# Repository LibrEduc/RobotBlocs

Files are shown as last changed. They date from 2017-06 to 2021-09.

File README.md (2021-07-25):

RobotBlocs
===================
tangible programmation of drawing robot, by kids for kids.

[Click here to launch video: https://mediacad.ac-nantes.fr/m/2332](https://mediacad.ac-nantes.fr/m/2332)
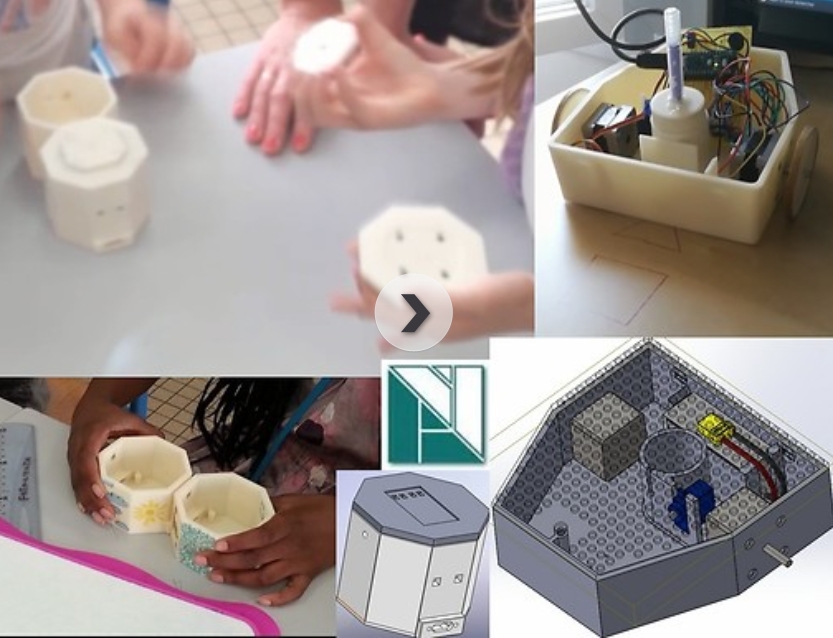
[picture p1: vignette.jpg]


**==>**[**Animation à ouvrir.**](https://github.com/technologiescollege/RobotBlocs/blob/master/principe.swf?raw=true)

Designers & developpers
----------
Chaque version du projet, chaque année, chaque groupe et chaque organisation a été différente.
Vous trouverez les noms des élèves, quand ils ont bien voulu qu'on les laisse, dans les dossiers (électronique ou Modeles_3D\Solidworks) de chaque année.

Each version of the project, each year, each group and each organisation has been different.
You will find the names of the students, when they were willing to be left, in the folders (electronic or Modeles_3D\Solidworks) of each year.

Explanation/explication
----------
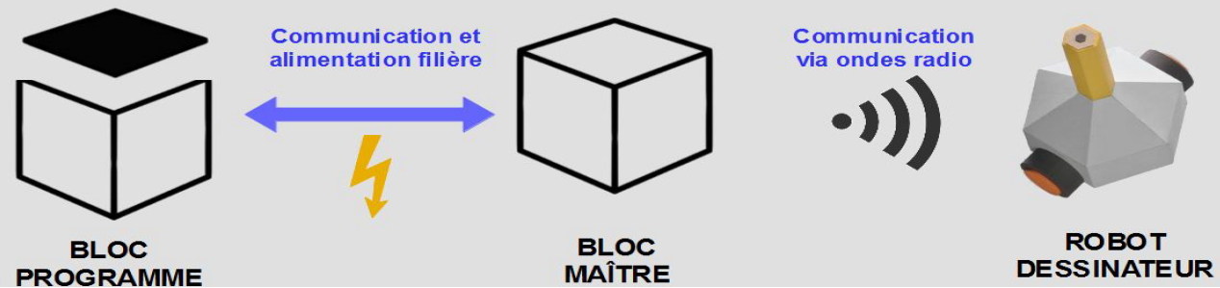
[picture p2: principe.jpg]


Les enfants jouent naturellement avec leurs mains et apprennent avec dès leurs premières années, construisant toute sorte de choses qui peuvent les amuser mais aussi en faisant ces choses ensemble. Un des avantages de la programmation tangible est qu'il rend l'idée du programme physique, afin que les enfants puissent jouer avec, le manipuler et refaire autant que voulu avant de le téléverser. La tranche d'âge visée est celle d'enfants entre 6 et 7 ans. 

Notre problématique est la suivante : "concevoir un système permettant à des enfants âgés de 6 ans ou plus, sachant lire ou pas, avec des difficultés motrices ou pas, d'apprendre les bases de la programmation et de l’algorithmique". 

A la suite de la lecture du cahier des charges fonctionnels, nous pouvons donc affirmer que nous devons concevoir un système composé de 3 sous-systèmes : 

 - un bloc maître qui transmet les informations des blocs programmes à un robot dessinateur.  
 - des blocs programmes qui auront une fonction, liée aux mouvements du robot,définie par un couvercle amovible ainsi qu'une capacité à s'emboîter entre eux afin de former une chaîne pour transmettre l'information. 
 - un robot dessinateur motorisé autonome en énergie qui possédera une partie mobile pour déplacer un crayon, d'un diamètre de 8mm à 15mm, afin de tracer des formes sur papier. Il exécutera les commandes des blocs programmes envoyées via le bloc maître.

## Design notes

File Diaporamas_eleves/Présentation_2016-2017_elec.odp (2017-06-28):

## Projet Blocs Lycée Livet -STI2D

<number>

## Présentation

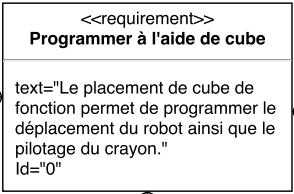
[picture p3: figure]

Développer la créativité et la réflexion.

Enfant de 5 à 6 ans.

Co-réalisation avec les ITEC.

<number>

## Présentation du projet.

COUVERCLE

BLOC

MAÎTRE

ROBOT

BLOC PROGRAMMABLE

<number>

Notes: décompose en 3 parties : couvercle interchangeable → ex: fct 2 = triangle donc la fonction résultante est faire un triangle quand couvercle sur bloc maître.

## Vidéo tutorial

<number>

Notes: Enfants vont créer une séquence en empilant les blocs les uns à la suite des autres. Rattaché au bloc maître Enfants vont enclencher le processus de démarrage. Bloc maître va compter le nombre de bloc et récupérer les fonctions dans l’ordre. Envoie au robot. Il va pouvoir reproduire les fonctions sur une feuilles de papier.

## Le robot

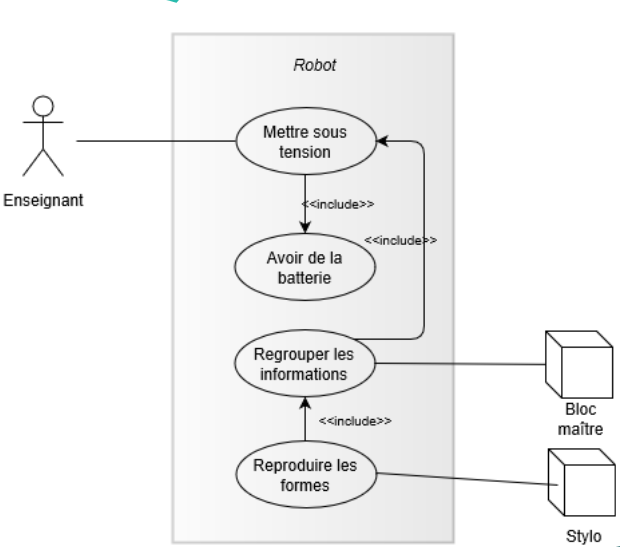
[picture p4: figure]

Diagramme de cas d’utilisation

<number>

## Le robot

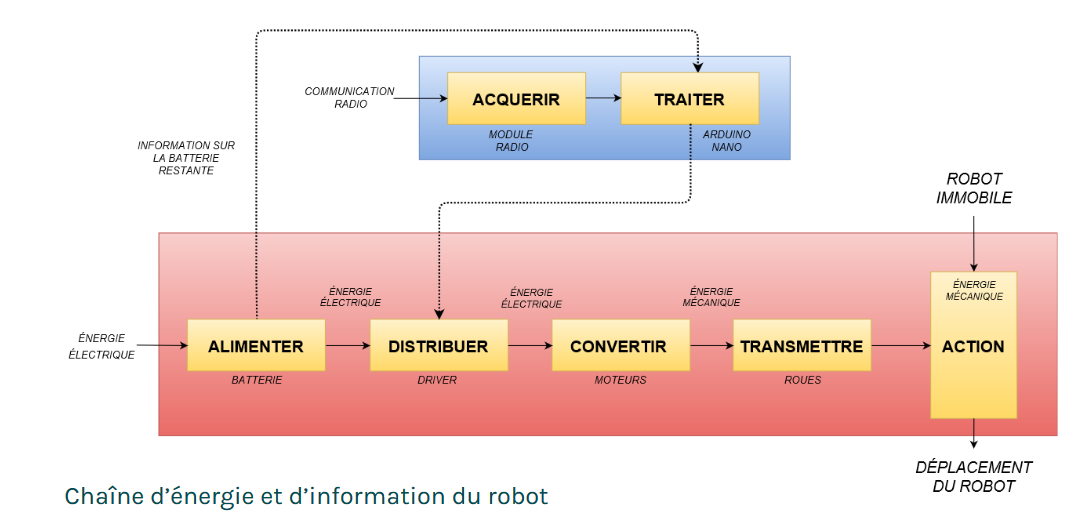
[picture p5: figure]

Chaîne d’énergie et d’information du robot

<number>

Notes: Acquérir communication radio pour programme. Arduino nano va traiter….

## Exigence numéro 1

Bloc maître

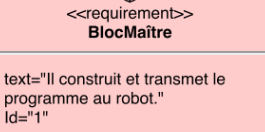
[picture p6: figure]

Le robot

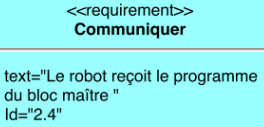
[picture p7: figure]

<number>

## Choisir une communication adaptée.

- SANS FIL
- DISTANCE

<number>

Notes: EXIGENCES

## 2. Hypothèses

| Bluetooth (HC-05) | Radio (NRF)
Tension | 5V | 3,3V
Fréquence (bande ISM) | 2,4 GHz | 2,4 GHz
Vitesse max | 2,1 Mbps | 2,1 Mbps
Distance max | 10 mètres | 250 mètres
Taille | 26,9 x 13 | 29 x 15 mm

<number>

## 3. Expérimentation bluetooth

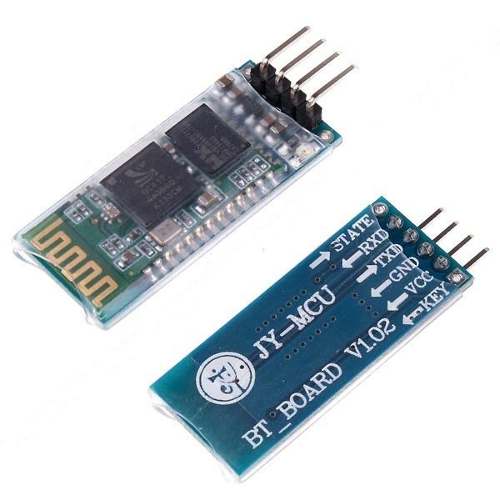
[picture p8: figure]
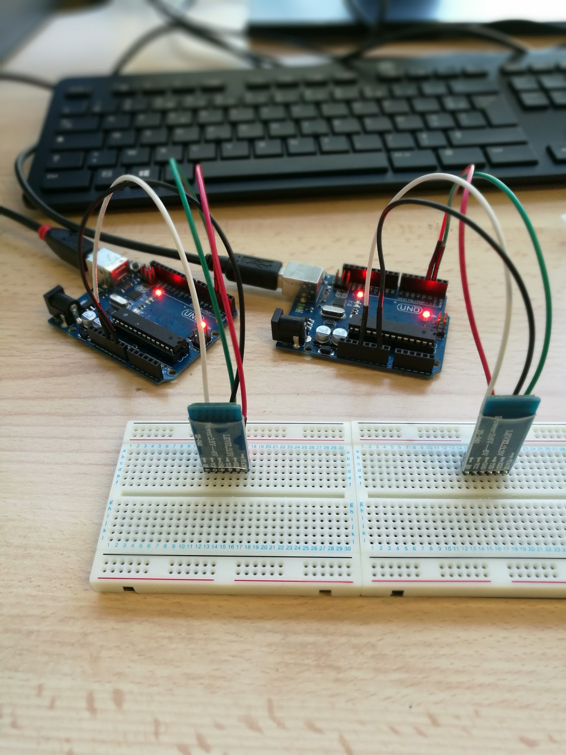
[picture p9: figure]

VCC | 5V
GND | GND
TX | Digital
RX | Digital

Protocol RS-232

Émetteur

Récepteur

<number>

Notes: deux module identique, en tant qu’E et R. Communication RS-232 Appareille pas automatiquement, Étape manuelle,demanderai d’ouvrir le boîtier à chaque utilisation.

## 4. Expérimentation radio

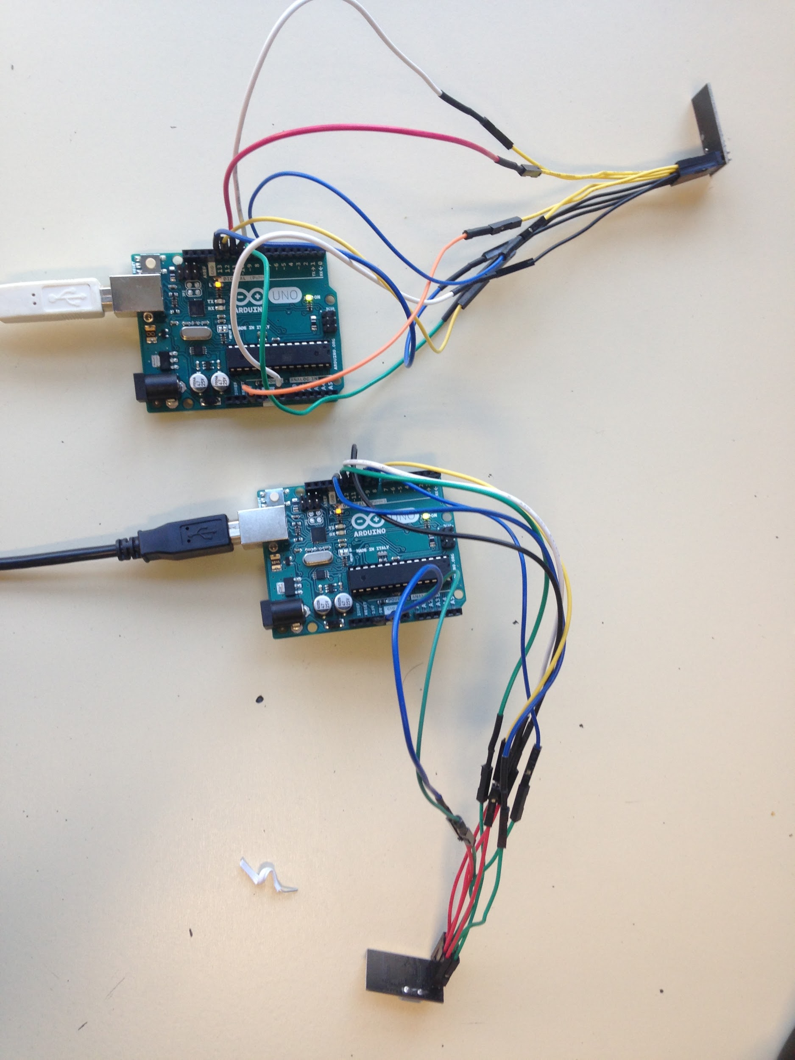
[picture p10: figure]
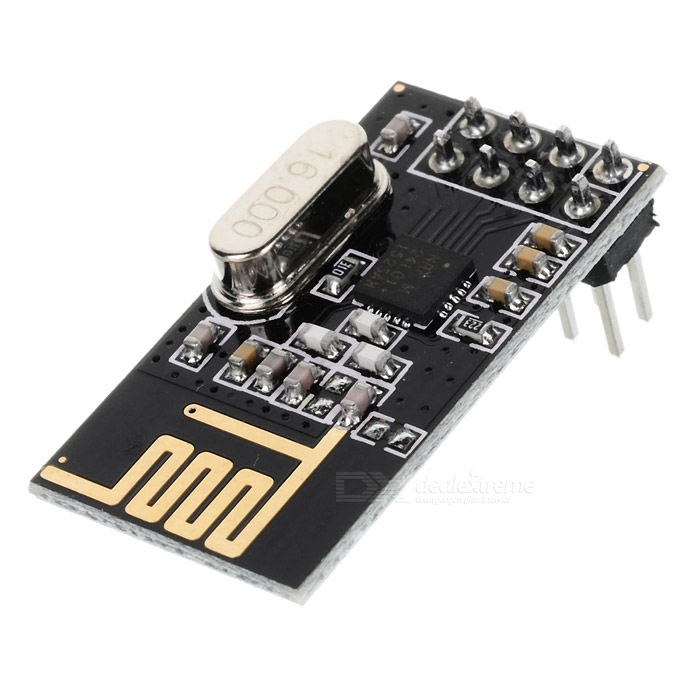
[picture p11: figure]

Émetteur

Récepteur

VCC | 3,3V
GND | GND

CE | SCK | MOSI
MISO | CSN | IRQ

Protocol SPI

<number>

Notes: Même fonctionnement que le bluetooth Communication SPI Échange de données MISO : Master Input Slave Output MOSI : Master Output Slave Input SCK : SPI serial clock CSN : séléction du module

## 5. Fonctions

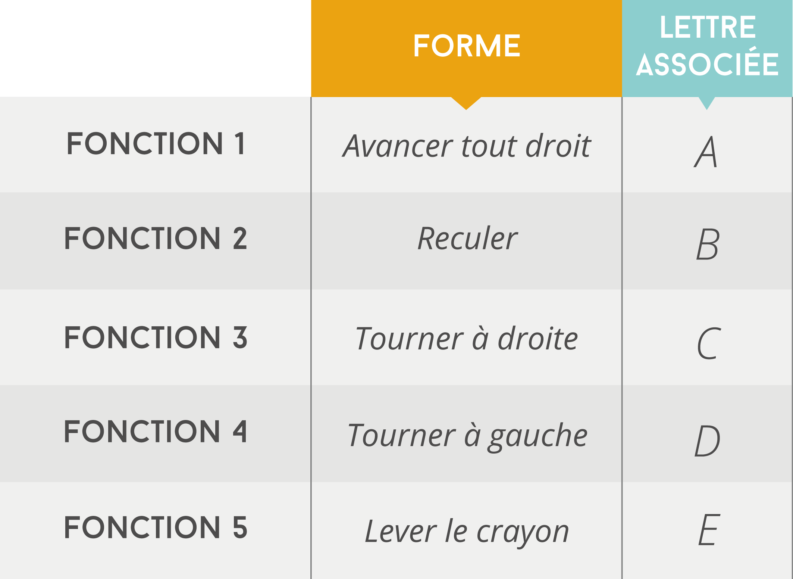
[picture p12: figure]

Exemples des 5 premières

fonctions les plus simples.

<number>

## 6. Algorithme liaison radio

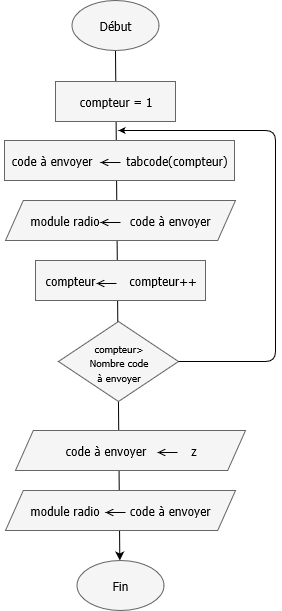
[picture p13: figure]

BLOC

MAÎTRE

Émetteur

“Permet d’envoyer le code au robot.”

<number>

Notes: Avant, le bloc maître à récupérer chaque fonction et classer dans un tableau. Envoyer colonne par colonne. “caractère par caractère” Une fois compteur supérieur au nombre de ligne à envoyer, algo terminé. La lettre “Z” signifie la fin de la boucle, la séquence, la fin du programme.

## 7. Algorithme liaison radio

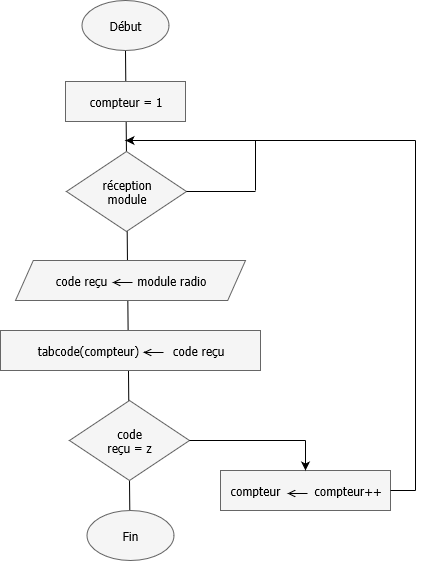
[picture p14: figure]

ROBOT

Récepteur

“Permet de recevoir le code du

Bloc maître.”

<number>

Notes: Le robot attend la réception. TRAVAIL INVERSE On va replacer chaque ligne reçu dans un tableau. Chaque caractère dans un tableau. Une fois le caractère “Z” reçu, le robot peut arrêter la communication, le code a été stocké.

## Exigence numéro 2

Robot

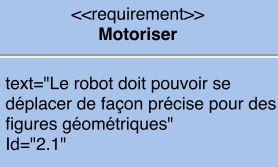
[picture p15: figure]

<number>

## Notre choix

Moteur pas à pas

Précision pour réaliser des formes avec un angle de 0,9°.

Motoréducteur

Précision plus approximative.

Variation entre la vitesse et le temps.

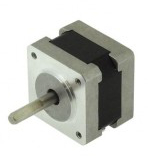
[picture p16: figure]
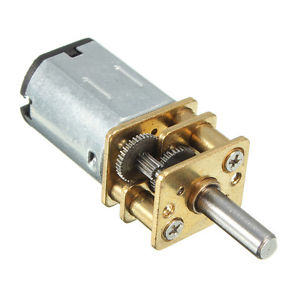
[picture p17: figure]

<number>

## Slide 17

Le moteur

Pas à pas.

400 pas par tour

10V

Couple 0,107 N.m

Pas de 0,9°

120g

<number>

## 2. Fonctionnement du moteur Pas à Pas

→ transformer une impulsion électrique en un mouvement angulaire.

PAS de 0,9°

0,9 x 400 = 360° = 1 tour

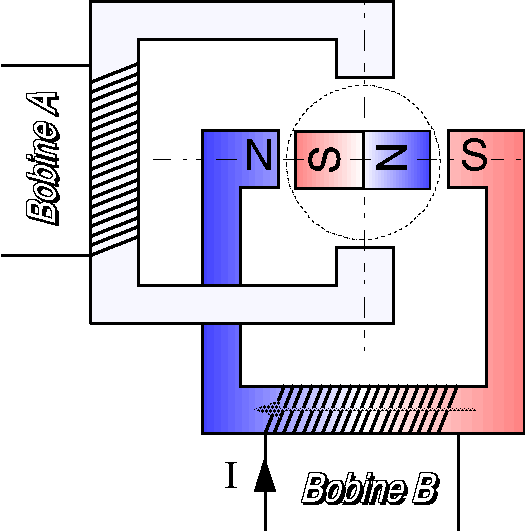
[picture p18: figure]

<number>

## 3. Piloter le moteur à l’aide du Driver

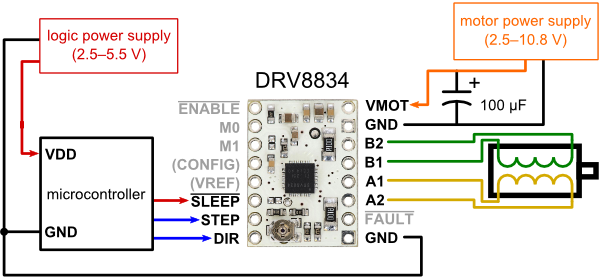
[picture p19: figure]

Batterie

Moteur pas-à-pas

Arduino

<number>

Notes: SLEEP → mettre en veille. STEP → nombre de pas. DIR → varier sens de rotation du moteur.

## 4. Algorithme du robot

ROBOT

“Processus du robot pour réaliser les

fonctions.”

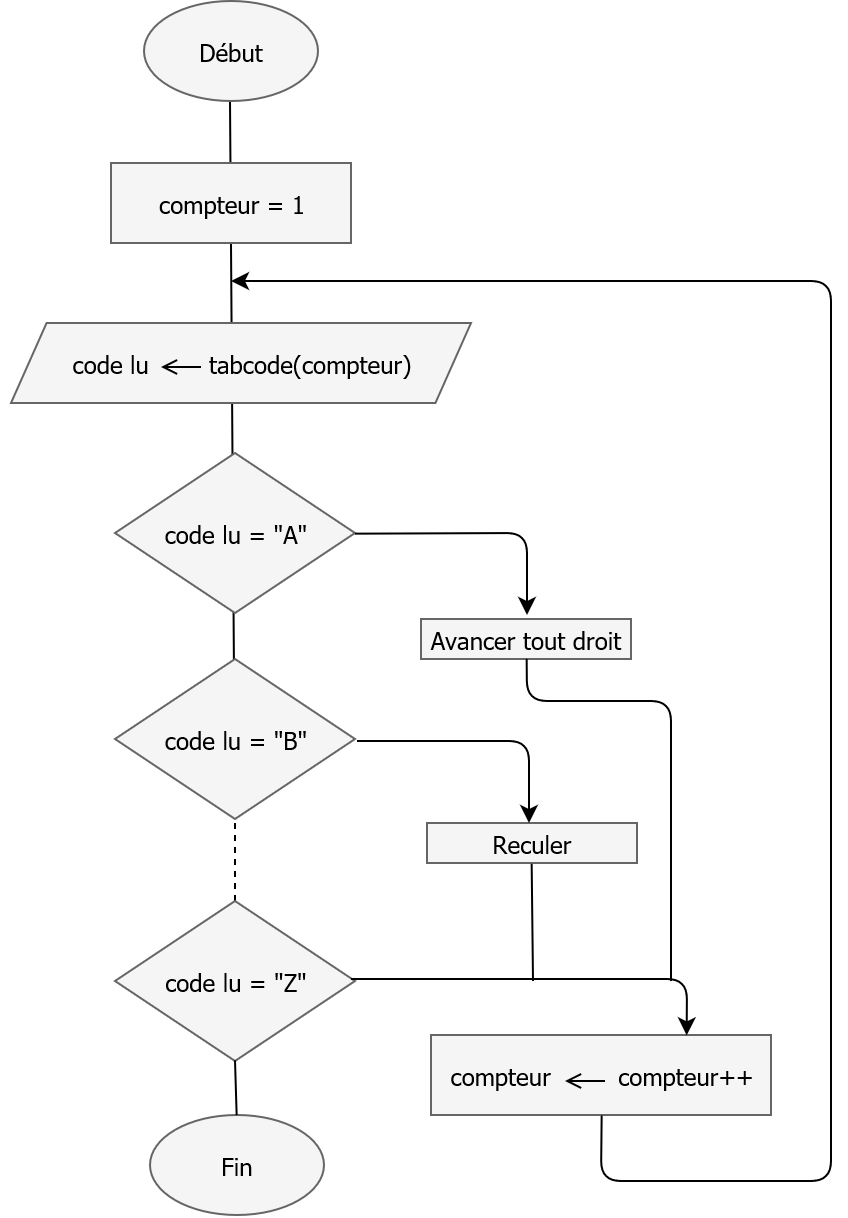
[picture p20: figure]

16 fonctions

<number>

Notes: Suite d’instruction que le robot va exécuter. Une fois toutes que toutes les informations ont été stockés dans un tableau. Lire le code reçu, le tableau : Passé en revue les 16 fonctions, et les exécuter toujours dans l’ordre demandé.

## Synthèse

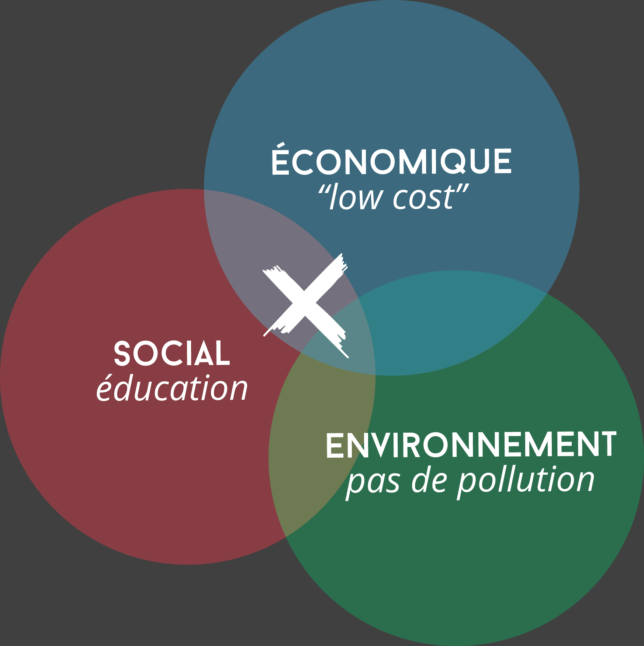
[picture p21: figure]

Amélioration du prototype :

Microprocesseur + petit, - cher

Communication Wifi

Amélioration du design

Créer de nouvelle fonction

Trouver composants encore - cher

Énergie propre : panneau solaire

<number>

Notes: Axe équitable. “Low cost” → qualité mais a pris raisonnable dans le choix des matériaux. Composant peu chère pour faciliter l'accessibilité. Pas d’énergie polluante → Énergie électrique rechargeable (panneau solaire pour recharger, ou éolien impacter les enfants sur les solutions énergétiques qui respecte l'environnement.

## Module radio

Émetteur

<number>

## Module radio

Récepteur

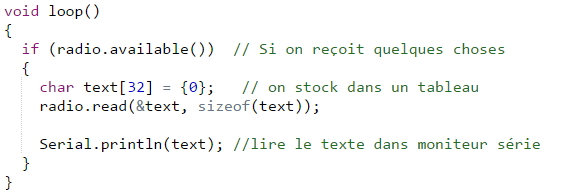
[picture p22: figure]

<number>

## Robot, exemple fonction carré

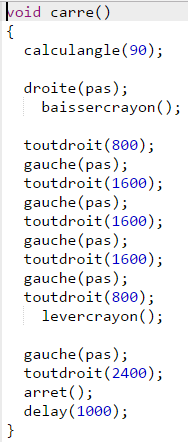
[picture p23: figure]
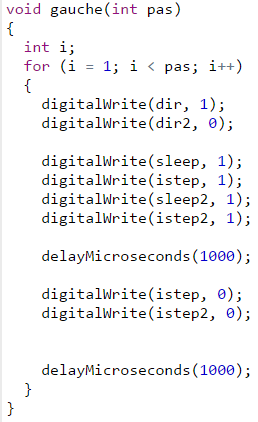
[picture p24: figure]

<number>

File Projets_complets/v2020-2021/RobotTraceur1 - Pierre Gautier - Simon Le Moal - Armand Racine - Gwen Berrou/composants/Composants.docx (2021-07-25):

Composants:

Consommation mA

Périphérique de communication bluetooth:

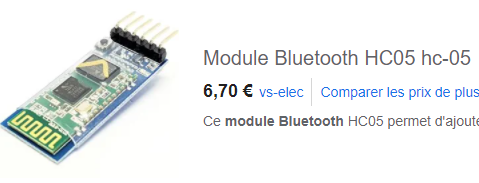
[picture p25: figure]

Pour communiquer avec le module de commande

Lien du site (https://www.gotronic.fr/art-module-bluetooth-hc05-26097.htm)

Nous avons choisis ce module bluetooth car il est de petite taille et il peut se connecter facilement à la carte de commande

Carte de commande

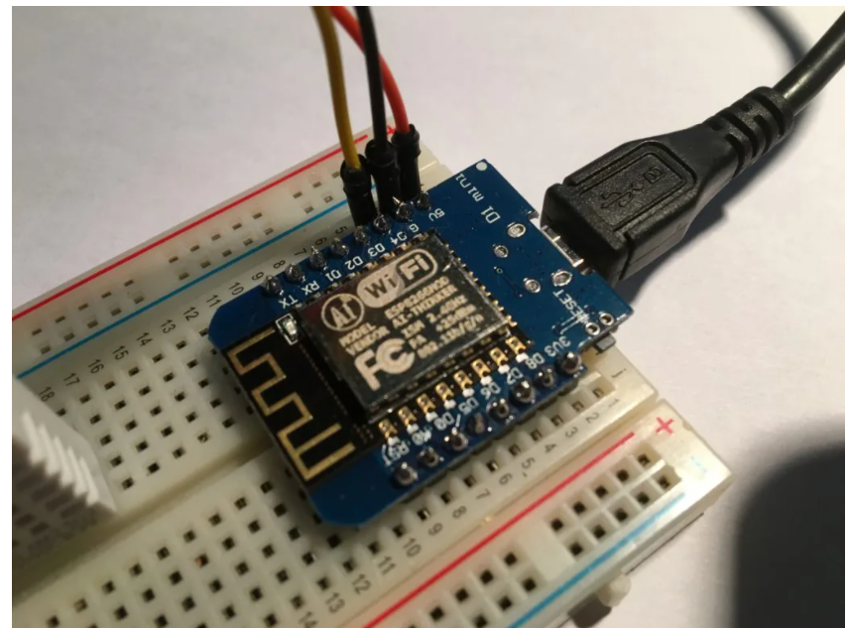
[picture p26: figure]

Lien du site (https://www.gotronic.fr/art-module-esp8266-25664.htm)

Nous avons choisis la carte Wemos D1 mini ESP8266

car elle est petite et comprend des langages simples

commande de moteur:

lien du site (https://www.gotronic.fr/art-commande-de-2-moteurs-cc-drv8833-2x1-2a-21757.htm)*

Led représentation du niveau de charge


Lien du site (https://www.gotronic.fr/art-led-rgb-5-mm-ll509rvb-32781.htm)

Nous souhaitons utiliser des Led pour indiquer un niveau de charge pour notre robot. La Led RGB choisie nous permet d’afficher n’importe quelle couleur voulue en plus de ne pas prendre beaucoup de place et d’être bon marché.

# Moteur à courant continu RS PRO,


Lien du site (https://www.gotronic.fr/art-motoreducteur-1094-22287.htm)

Ce moteur parfait car très petit et assez puissant pour pouvoir faire fonctionner notre robot.

# Batterie LiPo 3,7 Vcc 1,8 Ah MB-P3090003 50 x 33 x 10 mm


Lien du site (https://www.gotronic.fr/art-batterie-lipo-3-7-vcc-1-8-ah-mb-p3090003-28485.htm)

Cette batterie permet d’avoir l’autonomie nécessaire à notre robot tout en ne prenant pas beaucoup de place.

roue libre ½


lien du site (https://www.gotronic.fr/art-roue-libre-1-2-953-21790.htm)

# Servomoteur DMS-MG90


lien du site (https://www.gotronic.fr/art-servomoteur-dms-mg90-32266.htm)

joint torique


lien site (https://www.orexad.com/fr/joint-torique-ou-nbr-90-noir/p-G1085010966)

vis M1,6*5


lien lot de vis (https://www.gotronic.fr/art-10-vis-acier-m1-6-33234.htm)

https://thepihut.com/products/mini-solderless-breadboard-4x4-points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

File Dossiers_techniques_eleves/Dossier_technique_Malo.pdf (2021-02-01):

## DOSSIER TECHNIQUE DU PROJET DE TERMINALE


## Malo VIEILLET

## ROBOBLOCS (partie robot)

Terminale STI2D 7 | 2016-2017

### Sommaire

### Page de garde | Page 1

### Sommaire | Page 2

### Introduction | Page 3

### Exploration du projet et recherche de limites d'études

Cahier des charges | Page 4
Chaînes d'énergies | Page 5
Normes et brevets | Page 6

### Conception préliminaire

Formes blocs programmes | Page 7
Prototypage et tests | Pages 7,8
Forme robot | Page 8
Stylo : maintien et déplacement | Pages 9,10

### Conception détaillée

Robot | Pages 11,12
Choix du matériau | Page 12
Tests de résistance des matériaux | Page 13
Rhéologie | Page 14,15

### Annexes

Diagramme d'exigences | Page 16
Diagramme de cas d’utilisation | Page 17
Diagrammes de Gantt | Page 18
Malo VIEILLET, TSTI2D 7 2016 – 2017 | 2

### Introduction

Ce dossier à pour objectif d'expliquer notre projet technologique qui a été mené durant l'année 2016 – 2017. Il a été réalisé grâce à deux équipes :

- L'équipe ITEC ( Théo GAUTIER ; Haithem AOUADI et Malo VIEILLET) ➔ Travaille sur l'aspect mécanique et matériel du projet.
- L'équipe SIN ( Sullivan LE TOUZIC ; Pierre NICOLAS ; Martin POREE ; Hugo DENIER )
➔ Travaille sur la partie électronique et communication du projet.

Il sera divisé en plusieurs parties allant de la définition même du projet jusqu'à la rhéologie des pièces réalisées.

Ce projet est une étude industrielle : nous devons donc avoir l'approche appropriée pour le réaliser.

Dans ce dossier la partie sur le sous-système ''robot'' que j'ai réalisé, a été privilégiée.
Si vous souhaitez avoir plus d'informations sur la conception des autres sous-systèmes, je vous invite à consulter les dossiers techniques de mes camarades.

## Problématique

## ''L'objectif de ce projet est de concevoir un système

permettant à tout enfant âgé de 6 ans ou plus,

## d'apprendre les bases de la programmation et de

l’algorithmique''.

### Exploration du projet et recherche des limites de l'étude

Pour se projet, le cahier des charges suivant nous a été imposé. «Voir annexe 1»

Cahier des charges

A la suite de la lecture de ce diagramme, nous pouvons donc affirmer que nous devons concevoir un système composé de 3 sous-systèmes

- Un bloc maître qui transmet les informations des blocs programmes à un robot dessinateur et qui alimente les blocs programmes en énergie.
- Des blocs programmes qui auront une fonction, liée aux mouvements du robot, définie par un couvercle amovible ainsi qu'une capacité à s'emboîter entre eux afin de former une chaîne pour transmettre l'information.
- Un robot dessinateur motorisé autonome en énergie qui possédera une partie mobile pour déplacer et maintenir un crayon, d'un diamètre de 8mm à 15mm, afin de tracer des formes sur un support papier. Il exécutera les commandes des blocs programmes envoyées via le bloc maître.

Schéma du système


Afin de clarifier nos explications, voici un diagramme de cas d'utilisation suivit de schémas sur les chaînes d'énergies des 3 sous-systèmes.

Diagramme de cas d'utilisation

«Voir annexe 2»


Chaîne d'énergie du Robot

Chaîne énergie bloc maître

Chaîne énergie blocs programme

Ordre
(bloc maître) | Ordre

Ordre

Ordre

Le diagramme de Gantt suivant a été réalisé afin de répertorier les tâches que nous avons effectués. Il a donc été complété jusqu'à la date de sa dernière mise à jour pour ce dossier (03/05/2017).

Diagramme de Gantt

«Voir annexe 3»

Normes et brevets

Dans celui-ci, les tâches ont été réparties entre Théo, Haithem et moi-même.
La première partie sur l'exploration et la recherche des limites de l'étude a été réalisée ensemble.
La seconde sur la conception préliminaire a été réalisée individuellement (une fois la partie commune finie), avec une entraide afin de partager nos connaissances. La troisième sur la conception détaillée (réalisation numérique des pièces), a été faite individuellement : le système étant composé de 3 sous-systèmes, chacun travailla sur un sous-système (Haithem sur le bloc maître ; Théo sur les blocs programmes et moi-même sur le robot).

Pour ce projet, des recherches sur des limites d'étude, tel que des brevets ou normes, ont été faites. Par chance, aucun système similaire au notre n'a été breveté mais en revanche, plusieurs normes relatives à la sécurité des jouets dans le milieu scolaire on été trouvées. Elles concernent :

- La toxicité des jouets et de l'air dans le milieu scolaire
- La sécurité des jouets et du mobilier scolaire
- La santé des enfants

Nous tenons donc à impérativement respecter ces normes afin de garantir la sécurité et la santé des enfants.

### Conception préliminaire

Forme blocs programmes

Le début de cette partie a été réalisée en commun. Nous avons commencé par réfléchir ensemble sur la forme et la taille des blocs programmes et maître afin de définir la ''base du projet'', base sur laquelle Haithem et moi pouvons nous appuyer.
Nous avons également défini des fonctions que le robot pourra effectuer et qui seront représentées sur les couvercles interchangeables des blocs programmes. _________

Prototypage et tests

Nous avons donc simplement réalisé des premiers prototypes à base de polystyrène afin de pouvoir évaluer ces critères au près d'une classe d'enfants dans une école primaire.


Prototypes en mousse +
couvercles en carton


Les prototypes sont donnés aux enfants pour qu'ils
puissent voter la forme qui leur semble la plus adaptée.

La représentation des
fonctions est également
évaluée.

Les formes des blocs et la représentation des fonctions choisies ont été retenues.


Ce travail réalisé ensemble a permis de savoir sur quelle forme de bloc Théo et Haithem doivent développer leurs études et quelles fonctions doivent-ils représenter. Il me permet également de connaître les fonctions demandées, et donc, les mouvements que le robot doit réaliser.
_________

Forme robot

La première étape de conception du robot consiste à choisir sa forme principale : il faut qu'elle soit ludique, pratique, résistante, sécurisée tout en restant simple pour l'optimisation de l'espace. Il faut donc récapituler le matériel que le groupe SIN a besoin de mettre à l'intérieur du robot (moteurs, modulateur ESC, carte arduino, batterie). Il sera équipé d'un couvercle amovible afin de pouvoir accéder à la batterie. Il aura la même forme que la base du robot.

Roue libre; Le trou doit être aligné avec l'axe des roues afin de garantir un tracé précis pour une rotation par exemple; Les lignes en rouge représentent le conduit pour le stylo; Schéma de la forme retenue

Une forme de trapèze nous paraît adapté car elle est intuitive pour l'enfant (repère du sens de la marche) et permet une bonne stabilité du robot.

Nous choisissons un nombre de deux moteurs car la consommation, la simplicité de programmation et la nécessité de deux roues motorisés s'imposait pour pouvoir réaliser les figures demandées. Nous rajouterons une roue libre à l'avant afin de créer un système isostatique (trois appuis). Le choix du type de moteur sera fait par le groupe SIN.
_________

Stylo : Maintien et déplacement

Une fois cette forme de trapèze choisie,

Tube translatant; Vue de dessus; Mors à ressort; Vue 3d; Chassis

l'étape suivante est de réfléchir au système de maintient et déplacement du stylo. Un premier système de mors à ressort maintenant le stylo a été imaginé.


Mors à ressort

Chassis

Tube translatant

Système pignon
+ crémalière

Tube de maintient
(Chassis)

Cette solution a été abandonné durant la conception numérique du robot car elle présentait trop de contraintes techniques et de fabrication ainsi qu'une trop grande complexité.
Suite à cela, un système de maintient simplifié nous semble bien plus évident : il suffit de disposer un tube en caoutchouc adapté au diamètre du stylo avec une collerette pour le retenir, qui vient s'insérer dans le tube translatant. Plusieurs de ces pièces seront fabriquées avec un diamètre interne différent correspondant à

celui du stylo.; Chassis; Tube de maintient (Chassis); Tube translatant; Cylindre de guidage (Tube translatant)

Pour le déplacement, le système pignon/crémaillère a été remplacé par un levier actionné par un servomoteur. Ce levier déplace le tube grâce à un cylindre qui est une extrusion de celui-ci.

Le placement des autres pièces se fera pendant la conception détaillée car les possibilités de placement sont multiples. Nous préférons donc les modéliser en premier afin de mieux visualiser les tailles des objets (certains n'étant pas en notre possession, nous ne pouvons que seulement nous référencer aux données du constructeur).

Tube en
caoutchouc

Servomoteur

Levier

### Conception détaillée

Conception du robot
Dans cette partie commence donc la conception numérique du sous-système ''robot''. Il nous faut donc, dans un premier temps, réaliser les pièces que le robot va accueillir : la batterie, les deux moteurs pas à pas, ainsi que le servomoteur.
Une fois les pièces réalisées, nous attaquons le châssis du robot : il s'agit de la carcasse qui viendra accueillir toutes les pièces.
Suite à cela, nous passons directement à la conception de la partie maintien et déplacement du stylo afin d'évaluer l'espace qui lui sera nécessaire. Il faut optimiser l'espace car les moteurs doivent pouvoir être insérer lors de l'assemblage.

Bien que ce robot, ainsi que le reste du projet, soient l'objet d'une étude industrielle, nous devons veiller à la possibilité de fabriquer un prototype final grâce à une imprimante 3d : il nous faut donc prendre en compte les dimensions du robot afin qu'il

soit réalisable.

Nous souhaitons utiliser l'espace disponible à l'arrière du robot pour accueillir la batterie (1). Celle-ci doit être rechargé indépendamment du robot : elle doit donc pouvoir être facilement retirée de celui-ci. Un système de clips (2) nous paraît adapté car il permettra de maintenir la batterie en place tout en subissant des secousses. Il permet également de pouvoir l'enlever facilement. Une étude sera menée sur ces clips.
L'espace disponible à l'avant du robot sera utilisé pour placer la carte (arduino nano + carte d'accueil) (3) qui sera surélevée afin d'éviter tout contact entre le dessous de celle-ci et le châssis ainsi que les tiges de maintien de la roue libre.

Quatre extrusions avec un pas de vis (4) serviront à maintenir la carte en place. Un orifice est prévu pour accueillir l'interrupteur ON/OFF (5).
Le couvercle sera fixé en trois appuis : deux extrusions à l'arrière qui viennent s'insérer dans des encoches faites dans le châssis du robot (6) ainsi qu'un perçage à l'avant (7) afin d'accueillir une vis.
La roue libre sera placé à l'avant, sous la carte électronique (8).
La partie de maintien du servomoteur (9) sera tangent avec le cercle de support. Le levier poussera la tige du tube de maintien qui sera guidé par la gorge (10).

Pour les roues du robot, nous utiliserons des roues du commerce (75mm de diamètre) afin d'assurer une linéarité maximale du robot. Les dépouilles étant de 1,15°, l’inclinaison des roues ne sera pas préoccupante.

Afin de garantir l'éveil des enfants, des extrusions de type LEGO ont été créés afin de pouvoir y insérer des briques du constructeur. Il s'agit ici d'un supplément de réalisation qui ne nous était pas imposé mais il a été réalisé car sa conception était rapide et non complexe.
_________

Choix des matériaux
Afin de procéder à des tests numériques, il nous faut réfléchir à un matériau qui soit adapté pour les pièces à réaliser. Il nous faut donc un matériau qui respecte toutes les normes que nous avons rencontré sur notre étude : des conditions seront donc imposées pour la sélection (inflammabilité, résistance chimique, etc...). Le facteur coût sera également pris en compte car il s'agit d'une étude industrielle : il nous faut donc l'optimiser.

Après application des conditions, nous choisirons le thermoplastique PVC rigide car il s'agit du matériau le plus approprié de part sa conformité de nos conditions, mais également un respect de l'environnement très satisfaisant par rapport aux autres matériaux disponibles.
_________

Résistance des matériaux
Après l'application du matériau aux pièces, des études ont été menées sur la résistance des clips de la batterie car ils seront utilisés régulièrement (à chaque chargement de batterie). Un déplacement de 2mm sur chaque clip a été demandé car il s'agit de la longueur nécessaire afin d'extraire la batterie. Les résultats sont les suivants :


Suite à ces résultats, nous pouvons conclure que ces contraintes sont admissibles par la matière car l'effort demandé est faible. Il n'y a donc pas de risque de casse.

Après une application des dépouilles au châssis du robot, au levier ainsi qu'au tube de maintien, les pièces sont prêtes à être prototypées grâce à une imprimante 3d. Nous réaliserons de nouveaux tests en école avec le reste du système afin d'évaluer la fonctionnalité de l'ensemble au prêt des enfants.

Contrainte max : 7,2 MPa (N/mm²) | Contrainte max : 6,9 MPa (N/mm²)
F = 7,2 N | F = 6,9 N

Rhéologie

La partie rhéologie est importante car elle vient compléter l'étude industrielle de ce projet. Des études et simulations ont été réalisées sur les 3 pièces à réaliser : le châssis du robot, le tube de maintien, et le levier.


Cette simulation nous montre que la pièce peut être injectée en 1,9 sec max.
Une ligne de jonction est
présente (1) et des bulles d'air se forment à des extrémités. Elles sont peut préoccupantes car la pièce n'est pas soumise à des efforts importants.

Ici, le temps max est de 1,8 sec.
Le point d'injection à été placé à plusieurs endroits différents afin de voir le comportement de la matière lors de l'injection.
Ce test est le plus intéressant car une seule ligne de soudure est présente (1). Celle-ci est placé à un endroit peut contraint (ce qui n'aurait pas été le cas en 2).


2


Pour le châssis, le temps max est de 5,6 sec. Les bulles d'air et les lignes de soudure ne sont pas à des endroits préoccupants.
En revanche, on constate que pour les clips la matière s'arrête puis une fois le reste du moule remplit monte raidement vers le sommet des clips : cela peut être contraignant car la matière aura le temps de refroidir et de devenir plus visqueuse. Pour remédier à cela, une augmentation de la température du moule sera nécessaire afin de conserver la liquidité du plastique.


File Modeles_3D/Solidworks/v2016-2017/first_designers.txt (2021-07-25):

2016-2017 - Création des blocs et réalisation par les élèves de ITEC du LYCEE EUGENE LIVET / mechanical engineering :

 - AOUADI Haïthem,
 - GAUTIER Théo,
 - VIEILLET Malo.

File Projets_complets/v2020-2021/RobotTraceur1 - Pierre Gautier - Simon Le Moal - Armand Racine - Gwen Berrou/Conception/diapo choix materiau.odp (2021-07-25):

## Choix des matériau


## Comparaison


Sélectionnés :

1)Polypropylène

2)Polyphylène

## Comparaison


Sélectionnés :

1)Polypropylène

2)Polyphylène

## Matériau


Polypropylène

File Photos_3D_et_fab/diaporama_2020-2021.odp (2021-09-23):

## RobotBlocs concevoir un système permettant à des enfants âgés de 6 ans ou plus, sachant lire ou pas, avec des difficultés motrices ou pas, d’apprendre les bases de la programmation et de l’algorithmique


## RobotBlocs programmation tangible, par assemblage de blocs, d’un robot traceur


## RobotBlocs v2019-2020


## RobotBlocs v2020-2021 RobotTraceur1


## RobotBlocs v2020-2021 RobotTraceur2


## RobotBlocs v2020-2021 RobotTraceur4


## RobotBlocs v2020-2021 BlocsProg1


## RobotBlocs v2020-2021 BlocsProg2


Les blocsprog s’empilent comme des Lego, et le bloc maître doit glisser verticalement pour lire le code.

Projet original mais loin d’être abouti...

## RobotBlocs v2020-2021 BlocsProg3


Les blocsprog (wagons) s’enchaînent par aimantation, jusqu’au bloc maître (locomotive). Projet original mais pas abouti...

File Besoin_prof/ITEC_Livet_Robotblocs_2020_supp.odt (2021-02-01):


# Présentation


Depuis la réforme du collège, la programmation est entrée dans les programmes du cycle 3 et cycle 4, et permet d’initier les enfants à l’algorithmie, surtout en mathématiques pour leur faire créer des figures géométriques 2D simples. Le besoin est de pouvoir faire comprendre des notions de programmation en visualisant physiquement des déplacements grâce à un robot traceur, plus facilement appréhendables que des déplacements virtuels 'à la Scratch'.


Nous proposons un système physique de 'boîtes' utilisables par des enfants de 6~7 ans, qui vont s’enficher les unes aux autres en une suite d’instructions pour programmer les déplacements du robot.

# Découpage en sous ensembles

## Sous ensemble robot


Il s'agit de re-concevoir un robot pour représenter des figures géométriques créées par programmation. Celui-ci doit pouvoir faire son tracé sur une table et être suffisamment précis pour que, par exemple, un carré se referme bien.

Il devra pouvoir tenir un crayon/feutre/stylo classique, et le lever ou le descendre en position d’écriture à la demande. Il en existe déjà dans le monde du DIY :

## Sous ensemble BlocMaître

Un boîtier permettra de communiquer sans fil avec le robot, le détecter automatiquement et lui envoyer l’algorithme graphique (suite d'instructions suffisamment simples) préparé par les enfants.

Afin de recevoir le programme, il devra pouvoir recevoir en connectique un BlocProg et à travers une chaîne scanner la suite d’instructions qui deviendra le programme à téléverser.

## Sous ensemble BlocProg

Il s’agit d’un module (boîtier physique) qui symbolisera une instruction primaire de déplacement (avancer, tourner de 90°, etc) pour le robot, par des dessins ou logos. En emboîtant plusieurs de ces BlocProg on créera ainsi une suite d’instructions que le premier bloc (BlocMaître) pourra ensuite transférer au robot.

Chaque bloc devra se déclarer, s’enficher, être ergonomique et compréhensible immédiatement pour des enfants de 6~7 ans, sans nécessité de lecture. De plus il devra aussi posséder l’instruction en braille sur le boîtier pour un maximum d’accessibilité.

La solidité dans le respect des normes et la facilité d'utilisation sont primordiaux !

# Tâches

## Tâche 1 : BlocMaître

Analyser le diagramme des exigences SIN + ITEC

Reformuler des conditions d’utilisation SIN + ITEC

Utiliser une méthode de créativité SIN ITEC

Tracer le diagramme des cas d’utilisations SIN + ITEC

Communiquer avec le robot SIN

Communiquer avec le BlocProg SIN

Connecter avec le BlocProg SIN + ITEC

Conception du programme de déplacement du robot SIN

Alimenter les BlocProgs SIN

Réaliser des croquis et schémas normalisés ITEC

Choisir les matériaux et le mode d’obtention des pièces ITEC

Concevoir les pièces et les assemblages ITEC

Déterminer par simulation les sollicitations et la résistance des matériaux ITEC

Dimensionner/modifier les pièces en tenant compte des simulations ITEC

Fabriquer le prototype ITEC

Réaliser une procédure de mise en service SIN

Évaluer les coûts SIN + ITEC

## Tâche 2 : BlocProg

Analyser le diagramme des exigences SIN + ITEC

Reformuler des conditions d’utilisation SIN + ITEC

Utiliser une méthode de créativité SIN + ITEC

Tracer le diagramme des cas d’utilisations SIN + ITEC

Communiquer avec le BlocMaître ou le BlocProg SIN

Connecter avec le BlocMaître ou le BlocProg SIN + ITEC

Définir l’action du BlocProg SIN + ITEC

Signaler SIN + ITEC

Réaliser des croquis et schémas normalisés ITEC

Choisir les matériaux et le mode d’obtention des pièces ITEC

Concevoir les pièces et les assemblages ITEC

Déterminer par simulation les sollicitations et la résistance des matériaux ITEC

Dimensionner/modifier les pièces en tenant compte des simulations ITEC

Fabriquer le prototype ITEC

Réaliser une procédure de mise en service SIN

Évaluer les coûts SIN + ITEC

## Tâche 3 : Robot → déplacement

Analyser le diagramme des exigences SIN + ITEC

Reformuler des conditions d’utilisation SIN + ITEC

Utiliser une méthode de créativité SIN + ITEC

Tracer le diagramme des cas d’utilisations SIN + ITEC

Réaliser des croquis et schémas normalisés ITEC

Choisir les matériaux et le mode d’obtention des pièces ITEC

Concevoir les pièces et les assemblages ITEC

Déterminer par simulation les sollicitations et la résistance des matériaux ITEC

Dimensionner/modifier les pièces en tenant compte des simulations ITEC

Fabriquer le prototype ITEC

Déplacer le robot SIN + ITEC

Mesurer le déplacement SIN + ITEC

Comparer et critiquer le déplacement SIN + ITEC

Identifier les causes éventuelles et améliorer la conception SIN + ITEC

Alimenter SIN + ITEC

Évaluer les coûts SIN + ITEC

## Tâche 4 : Robot → crayon

Analyser le diagramme des exigences SIN + ITEC

Reformuler des conditions d’utilisation SIN + ITEC

Utiliser une méthode de créativité SIN + ITEC

Tracer le diagramme des cas d’utilisations SIN + ITEC

Réaliser des croquis et schémas normalisés ITEC

Choisir les matériaux et le mode d’obtention des pièces ITEC

Concevoir les pièces et les assemblages ITEC

Déterminer par simulation les sollicitations et la résistance des matériaux ITEC

Dimensionner/modifier les pièces en tenant compte des simulations ITEC

Fabriquer le prototype ITEC

Communiquer avec le bloc maître SIN

Tenir tout type de crayon ITEC

Déplacer le crayon verticalement SIN + ITEC

Mesurer la fiabilité du déplacement SIN + ITEC

Identifier les problèmes éventuels et améliorer la conception SIN + ITEC

Évaluer les coûts SIN + ITEC

ITEC_Livet_Robotblocs_2020_supp.odt Page 4 / 4


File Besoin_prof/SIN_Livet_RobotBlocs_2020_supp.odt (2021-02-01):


# Présentation


Depuis la réforme du collège, la programmation est entrée dans les programmes du cycle 3 et cycle 4, et permet d'initier les enfants à l'algorithmie, surtout en mathématiques pour leur faire créer des figures géométriques 2D simples. Le besoin est de pouvoir faire comprendre des notions de programmation en visualisant physiquement des déplacements grâce à un robot traceur, plus facilement appréhendables que des déplacements virtuels 'à la Scratch'.


Nous proposons un système physique de 'boîtes' utilisables par des enfants de 6~7 ans, qui vont s'enficher les unes aux autres en une suite d'instructions pour programmer les déplacements du robot.

# Découpage en sous ensembles

## Sous ensemble robot


Il s'agit de créer un robot pour représenter des figures géométriques créées par programmation. Celui-ci doit pouvoir faire son tracé sur une table et être suffisamment précis pour que, par exemple, un carré, un triangle se referme bien.

Il devra pouvoir tenir un crayon/feutre/stylo classique, et le lever ou le descendre en position d'écriture à la demande. Il en existe déjà dans le monde du DIY mais la précision n'est pas suffisante pour répondre à des exigences d'analyse géométrique et le stylo est fixe.

## Sous ensemble BlocMaître

Un boîtier permettra de communiquer sans fil avec le robot, le détecter automatiquement et lui envoyer l'algorithme graphique (suite d'instructions suffisamment simples) préparé par les enfants.

Afin de recevoir le programme, il devra pouvoir recevoir en connectique un BlocProg et à travers une chaîne scanner la suite d'instructions qui deviendra le programme à téléverser.

## Sous ensemble BlocProg

Il s'agit d'un module (boîtier physique) qui symbolisera une instruction primaire de déplacement (avancer, tourner de 90°, etc) pour le robot, par des dessins ou logos. En emboîtant plusieurs de ces BlocProg on créera ainsi une suite d'instructions que le premier bloc (BlocMaître) pourra ensuite transférer au robot.

Chaque bloc devra se déclarer, s'enficher, être ergonomique et compréhensible immédiatement pour des enfants de 6~7 ans, sans nécessité de lecture. De plus il devra aussi posséder l'instruction en braille sur le boîtier pour un maximum d'accessibilité.

La solidité dans le respect des normes et la facilité d'utilisation sont primordiaux !

# Diagramme des exigences


# Tâches

## Tâche 1 : BlocMaître

Analyser le diagramme des exigences SIN + ITEC

Reformuler des conditions d’utilisation SIN + ITEC

Utiliser une méthode de créativité SIN ITEC

Tracer le diagramme des cas d’utilisations SIN + ITEC

Communiquer avec le robot SIN

Communiquer avec le BlocProg SIN

Connecter avec le BlocProg SIN + ITEC

Conception du programme de déplacement du robot SIN

Alimenter les BlocProgs SIN

Réaliser des croquis et schémas normalisés ITEC

Choisir les matériaux et le mode d’obtention des pièces ITEC

Concevoir les pièces et les assemblages ITEC

Déterminer par simulation les sollicitations et la résistance des matériaux ITEC

Dimensionner/modifier les pièces en tenant compte des simulations ITEC

Fabriquer le prototype ITEC

Réaliser une procédure de mise en service SIN

Évaluer les coûts SIN + ITEC

## Tâche 2 : BlocProg

Analyser le diagramme des exigences SIN + ITEC

Reformuler des conditions d’utilisation SIN + ITEC

Utiliser une méthode de créativité SIN + ITEC

Tracer le diagramme des cas d’utilisations SIN + ITEC

Communiquer avec le BlocMaître ou le BlocProg SIN

Connecter avec le BlocMaître ou le BlocProg SIN + ITEC

Définir l’action du BlocProg SIN + ITEC

Signaler SIN + ITEC

Réaliser des croquis et schémas normalisés ITEC

Choisir les matériaux et le mode d’obtention des pièces ITEC

Concevoir les pièces et les assemblages ITEC

Déterminer par simulation les sollicitations et la résistance des matériaux ITEC

Dimensionner/modifier les pièces en tenant compte des simulations ITEC

Fabriquer le prototype ITEC

Réaliser une procédure de mise en service SIN

Évaluer les coûts SIN + ITEC

## Tâche 3 : Robot → déplacement

Analyser le diagramme des exigences SIN + ITEC

Reformuler des conditions d’utilisation SIN + ITEC

Utiliser une méthode de créativité SIN + ITEC

Tracer le diagramme des cas d’utilisations SIN + ITEC

Réaliser des croquis et schémas normalisés ITEC

Choisir les matériaux et le mode d’obtention des pièces ITEC

Concevoir les pièces et les assemblages ITEC

Déterminer par simulation les sollicitations et la résistance des matériaux ITEC

Dimensionner/modifier les pièces en tenant compte des simulations ITEC

Fabriquer le prototype ITEC

Déplacer le robot SIN + ITEC

Mesurer le déplacement SIN + ITEC

Comparer et critiquer le déplacement SIN + ITEC

Identifier les causes éventuelles et améliorer la conception SIN + ITEC

Alimenter SIN + ITEC

Évaluer les coûts SIN + ITEC

## Tâche 4 : Robot → crayon

Analyser le diagramme des exigences SIN + ITEC

Reformuler des conditions d’utilisation SIN + ITEC

Utiliser une méthode de créativité SIN + ITEC

Tracer le diagramme des cas d’utilisations SIN + ITEC

Réaliser des croquis et schémas normalisés ITEC

Choisir les matériaux et le mode d’obtention des pièces ITEC

Concevoir les pièces et les assemblages ITEC

Déterminer par simulation les sollicitations et la résistance des matériaux ITEC

Dimensionner/modifier les pièces en tenant compte des simulations ITEC

Fabriquer le prototype ITEC

Communiquer avec le bloc maître SIN

Tenir tout type de crayon ITEC

Déplacer le crayon verticalement SIN + ITEC

Mesurer la fiabilité du déplacement SIN + ITEC

Identifier les problèmes éventuels et améliorer la conception SIN + ITEC

Évaluer les coûts SIN + ITEC

SIN_Livet_RobotBlocs_2020_supp.odt Page 5 / 5

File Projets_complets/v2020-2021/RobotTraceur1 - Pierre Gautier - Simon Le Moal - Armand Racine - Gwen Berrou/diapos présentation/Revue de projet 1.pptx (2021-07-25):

## Revue de Projet n°1

Phase 1
Analyse du Besoin

## Présenter des Diagrammes SysML (contexte, BDD existant)


utilisateur

## Carte mentale (issue du Brainstorming)


problème lors du brainstorming:
1. forme et esthétique
2. répartition des blocs
3. mouvement
4. tracé du crayon

## Plans, Croquis et Dessins


## Tableau justifiant le choix de la solution

classement des trois diferente idées :

conclusion sur le choix de la solution ...

## Présenter le diagramme de typologie d’énergie des systèmes :


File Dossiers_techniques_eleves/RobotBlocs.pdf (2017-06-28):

# Présentation générale du projet

Le projet bloc consiste en la réalisation et la conception d’un jeu pédagogique destiné aux classes préparatoires (CP) et donc aux enfants agés de 5/6 ans.
Son objectif est de développer la créativité et la réflexion de l’enfant sous forme de jeu à un prix relativement accessible.
Ce projet est réalisé en 70 heures en coopération avec un second groupe : l’un s’occupant de l’intelligence embarquée et de l’énergie, tandis que l’autre à en charge la conception.
L’objectif final étant de déposer une licence afin de le protéger et potentiellement de le commercialiser. Fonctionnement :
Le système est divisé en trois parties distinctes : le bloc maître, le bloc programmable et le robot :

Sur les blocs programmables se fixent des couvercles interchangeables, qui ont différentes formes et représentent différentes actions : par exemple, si le couvercle représente un carré, alors une fois fixé sur le bloc, l’action résultante du bloc sera : “faire un carré”. Au total, 16 formes différentes ont été imaginées.

Les enfants vont créer une séquence en empilant les blocs les uns à la suite des autres à partir du bloc maitre.

Un fois fait, ils vont appuyer sur le bouton central du bloc maitre pour indiquer que la séquence est terminée.
Ce bloc va compiler les informations pour les communiquer au robot qui va reproduire les formes sur une feuille à l’aide d’un crayon accroché au préalable.

P.2

Répartition des tâches :

Le travail a été réparti de façon équitable et logique de façon à ce que le projet avance le plus vite possible et que chaque personne ait la même charge de travail.

Répartition des tâches
Qui ? | Quoi ? | Pourquoi ?
Hugo DENIER | -Communication bloc maitre --robot -Fonctionnement des moteurs -Choix des constituants | Hugo s’est occupé de la communication entre le bloc maître et le robot en réalisant plusieurs expérimentations pour savoir comment la réaliser. Il s’est également intéressé au fonctionnement des moteurs et donc au choix des drivers.


Martin PORÉE | -Calcul des batteries -Détection de la batterie -restante -Maquettage d’un robot 3D | Martin s’est occupé du choix de la batterie pour tenir une demi-heure et a réalisé un programme permettant de savoir le niveau de la batterie pour prévenir de la recharger. Il a également réalisé un robot imprimé à l’imprimante 3D afin de pouvoir effectuer des tests.


Sullivan LE TOUZIC | -Détection du couvercle -Réalisation des circuits -imprimés | Sullivan a réalisé un programme pour la détection du couvercle pour que le bloc programmable puisse connaître sa fonction. Afin de proposer un projet fini il a aussi réalisé des circuits imprimés pour chaque sous système.


Pierre NICOLAS | -Communication entre les blocs -Programme coeur : robot / -bloc -maitre / bloc -programmable -Réalisation des circuits -imprimés -Choix des constituants | En plus de la communication entre les différents blocs, je me suis chargé de réaliser le programme finale de chaque sous système. J’ai aidé au choix des constituants et à la réalisation des circuits imprimés.

Puisque les blocs sont destinés à être assemblés, une communication physique semble être adaptée. La communication permettra de connaître : le nombre de blocs, leur ordre et leurs fonctions.
Ainsi deux types de communications ont été retenues afin d’assurer ce rôle :
La communication I2C (cf. n°1 p9)
La communication RS232 TTL (cf. n°2 p9)
Le choix :
-On remarque que la liaison I2C nécessite un fils de moins que la liaison RS232, cependant cela n’est pas important car l’alimentation électrique empruntera la connexion : il y aura donc un + et un - à rajouter. Or la masse (-) existe déjà sur la liaison RS232. Il n’est donc pas nécessaire d’en rajouter une.
-Cependant, la liaison I2C nécessite quelque chose que l’on ne peut pas avoir. En effet, la liaison I2C fonctionne sur adresse. Chaque bloc à la programmation se verrait définir une adresse différente.
Si je veux parler au bloc 2, je dois appeler le bloc 2. Or comment savoir ou est le bloc 2 et s’il a bien été utilisé ? Cela n’est pas possible.
La communication RS232 TTL a donc été retenue, d’une part car elle répond au besoins de l’exigence qui était d’assurer une communication avec n’importe quel bloc mais aussi car il s’agit d’une communication que l’on connaît et que l’on a déjà utilisé en cours et en travaux pratique.
Comment s’y prendre ? :
La liaison RS232 TTL peut se faire de deux manières sur Arduino (carte de programmation cf. ci-dessous) :
-De manière matériel avec une puce intégré à Arduino (cf. encadré ci-dessous) qui peut gérer la -communication en même temps qu’en exécutant le programme sur seulement deux broches.
-De manière logiciel en n’utilisant n’importe quelle broches à l’aide d’une bibliothèque intégrée.
L’avantage de l’un par rapport à l’autre est que la liaison matérielle peut fonctionner en même temps qu’en faisant tourner le programme, cependant elle ne fonctionne que sur deux broches et notre montage en demande quatre. Nous devons donc choisir la manière logicielle
Quoiqu’il en soit la liaison RS232 TTL traduit le message de l’utilisateur en trame électrique binaire sur un octet interprétable par les deux cartes : 0 volt pour 0(état logique bas) et 5 volts pour 1(état logique haut) à la place de +12 volts et -12 volts pour la liaison RS232 de base.


# Conception détaillé

DE FÉVRIER À FIN MARS

La stratégie :

Une stratégie a été imaginé en deux étapes afin de réaliser la communication :
La première est de compter les blocs. L’informatique n’a pas d’oeil, ou du moins notre système n’en a pas. Pour savoir le nombre de bloc le système va jouer au “téléphone arabe”, un message va passer de bloc en bloc à partir du bloc maître jusqu'à arriver au dernier bloc qui n’aura plus personne à qui parler. Pour savoir s’il y a un bloc “2” à côté de lui, le bloc “1” va demander s’il y a quelqu’un à côté de lui. S’il y a un bloc “2” alors la réponse sera “oui” sinon aucune réponse ne sera reçu. Ce bloc sera alors le dernier bloc.


La seconde étape consiste à connaître la fonction de chaque bloc. Le “téléphone arabe” va repartir dans l’autre sens, cette fois ci, du dernier bloc au bloc maître. Chaque bloc va répéter à un autre la séquence qu’on lui aura chuchoté en y ajoutant sa propre fonction (traduit en lettre). De bouche à oreille, l’information finira par arriver au bloc maître qui aura alors toute les informations nécessaire.


Algorigrammes :

Le fonctionnement du bloc maître et celui du bloc programmable est légèrement différent. Les deux étapes de chaque bloc ont été représenté en quatre algorigrammes.
Etape 1 - Bloc maître (cf. p13):
Le schéma structurel du bloc maître se situe en annexe p23.
La communication se déclenche lors de l’appui sur le bouton central du bloc maître par l’enfant. Cela signifie que la séquence est terminé d’être construite. Dès lors le bloc maître envoie la lettre “Z” qui est le code simplifié de “es tu là ?” en attendant la réponse “Y” qui est le code simplifié de “Oui !” (cf. schéma 1 p11). Cela signifie qu’il y a bien un bloc à côté. L’étape 1 est terminé et on peut passer à l’étape 2. Cependant si l’on ne reçoit rien, cela signifie qu’il n’y a pas de bloc à côté et donc que le bloc maître est seul. L’appuis sur le bouton est surement une erreur, on redémarre la carte.
Etape 1 - Bloc programmable (cf. p13):
Le schéma structurel du bloc programmable se situe en annexe p22.
Le bloc programmable attend qu’on le contacte sur son entrée, c’est à dire par le bloc situé avant lui. Il attend la fameuse question (“Z”->”Es tu là?”) pour y répondre (“Y”->”Oui !”), avant d’effectuer à son tour la question au bloc situé après lui. S’il reçoit la réponse “Y” cela signifie qu’il y a bien un bloc après lui. L’étape 1 est donc terminé avec la première variante. Cependant s’il ne reçoit rien cela signifie qu’il est le dernier bloc de la séquence. L’étape 1 est donc terminé avec la seconde variante.
Etape 2 - Bloc programmable (cf. p13):
Le programme est adapté aux deux variantes et attend juste de savoir laquelle effectuer. Cette décision est prise lors de l’étape 1.
Variante 1 : Lors de la variante 1, cela signifiait que le bloc n’était pas le dernier de la séquence. Il attend donc de recevoir les informations du bloc situé après lui, pour les stocker tant qu’il en reçoit encore puis de les renvoyer au bloc situé avant lui, sans oublier d’ajouter sa propre fonction (cf. schéma 2 p11). Son rôle est à présent terminé et la carte redémarre afin de se réinitialiser.
Variante 2 : Lors de la variante 2, cela signifiait que le bloc était le dernier de la séquence. C’est donc à lui de commencer à envoyer sa fonction au bloc situé avant lui. Il ne recevra pas d’information car il n’y a pas de blocs situé après lui. Son rôle est à présent terminé et la carte redémarre afin de se réinitialiser.
Etape 2 - Bloc maître (cf. p13):
Le bloc maître est dans l’attente de recevoir l'information finale, celle combinant les fonctions de tous les blocs réunis. Il va stocker les valeurs tant qu’il en reçoit puis une fois fait pourra commencer l’émission radio afin de lui transmettre les informations..


# Prototypage et maquettage

D’AVRIL A LA FIN
Le prototypage :


Chaque liaison s’effectuera par un contact physique entre les deux blocs. Il y a donc deux faces possibles : Une face dite mâle(cf. ci-dessous à gauche) et une face dite femelle(cf. ci-dessous à droite).
Les aimants permettront de maintenir la connexion en place et donnera un côté attrayant au jouet.
Le bloc maître sera muni d’une face mâle et les blocs programmables d’une face mâle et femelle (voir ci-dessus).


Les connecteurs seront connecté à la carte. Un circuit imprimé à alors été envisagé afin de concrétiser le projet, de faciliter le câblage final et d’optimiser la robustesse du bloc (voir schéma en annexe p20).


Conception sur ordinateur avec Fritzing | Impression à échelle 1:1 sur transparent


L’impression des pistes se fait sur une plaque d'époxy qui est un matériau composé d’une couche de cuivre recouvert d’un revêtement résineux très sensible au UV. La préparation est simple, il suffit de placer le transparent sur la plaque du côté que l’on souhaite faire apparaître(1) puis de l’isoler dans une machine générant des UV pendant une durée d’environ 3 minutes(2). Il faut maintenant "révéler" la plaque dans une base forte, c’est à dire faire apparaître les pistes(3) avant de la plonger dans du perchlorure de fer qui va ronger le cuivre(4). Un dernier bain dans l’acétone permettra d’enlever les restes de résine(5) afin de faire apparaître le résultat final(6).


s
s

La plaque est ensuite percée minutieusement à la perceuse avec un foret de 0.8mm(7) afin de pouvoir y souder à l’étain(8) tous les composants nécessaire au bon fonctionnement du système(9).
Une fois tous les composants fixés, les circuits imprimés sont terminés. Il peuvent à présent être fixés dans les blocs prévus par le second groupe. Cependant, pour les tests, les blocs ne sont pas nécessaires

Les tests :

Le logiciel arduino embarque un moniteur série qui permet d'interagir avec son programme, notamment afin de surveiller son déroulement. Des lignes de codes ont donc étés insérés dans le programme afin de faire apparaître à chaque étape importante, du texte sur le moniteur série permettant ainsi de se situer dans l'exécution du programme.
Ordre de communication (voir p18):
Etape 1 :
B.M : “Attente de l’appuie sur le bouton” : Le bloc maître attend que l’utilisateur appuie sur le bouton. B.M : “Envoie de la lettre Z ”: le bouton a été appuyé, la lettre Z a été envoyé au bloc d'à côté (bloc 1). B.1 : “On ne reçoit rien ”: Le Z n’a pas encore été reçu.
B.1 : “Lecture de la lettre Z” : La lettre Z a été reçue du bloc précédent pour savoir si un bloc est là. B.1 : “Réponse par la lettre Y” : Le bloc est là, on répond par Y pour signaler la présence.
B.M : “Lecture de la lettre Y” : Un bloc est à côté, en attente.
B.1 : “Envoie de la lettre Z” : Le bouton a été appuyé, la lettre Z a été envoyée au bloc d'à côté (bloc 2). // même opération jusqu'à arriver au bloc 3
B.3 : “Envoie de la lettre Z” : Le bouton a été appuyé, la lettre Z a été envoyée au bloc d'à côté (bloc 4). B.3 : “Pas de réponse” : Cela signifie qu’aucun bloc n’est situé à côté.
Etape 2 :
B.3 : “Etat capteur” : On regarde sa fonction (voir tâche de Sullivan).
B.3 : “Envoie de ma fonction” : On envoie sa fonction traduit par une lettre comprise par tous les blocs. B.3 : “Redémarrage du bloc” : Le bloc a fini son rôle il peut redémarrer afin de se réinitialiser
// voir bloc 1
B.1 : “On reçoit quelque chose” : On reçoit les fonctions du bloc précédent.
B.1 : “Etat capteur” : On regarde sa fonction (voir tâche de Sullivan).
B.1 : “Envoie du caractère du bloc” : On envoit la fonction des autres blocs.
B.1 : “Envoie de ma fonction” : On envoie sa fonction traduite par une lettre comprise par tous les blocs. B.1 : “Redémarrage du bloc” : Le bloc a fini son rôle il peut redémarrer afin de se réinitialiser
// même opération jusqu'à arriver au bloc maître qui relaie l’information au robot
Légende : B.M = Bloc maître ; B.1 = Bloc 1 ; B.2 = Bloc 2 ; B.3 = Bloc 3


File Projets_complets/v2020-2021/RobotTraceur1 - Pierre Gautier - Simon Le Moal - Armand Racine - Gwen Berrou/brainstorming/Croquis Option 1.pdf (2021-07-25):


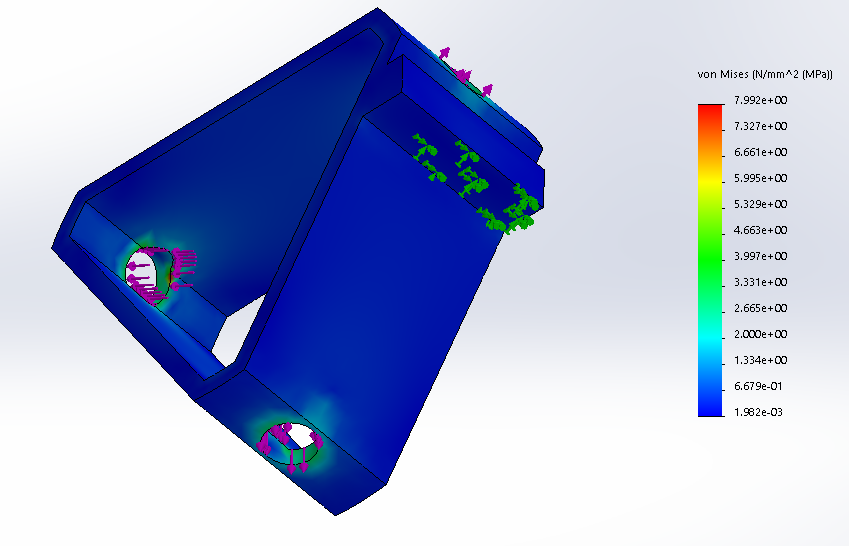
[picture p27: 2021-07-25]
Projets_complets/v2020-2021/RobotTraceur1 - Pierre Gautier - Simon Le Moal - Armand Racine - Gwen Berrou/Conception/Support Crayon/support crayon 2 taille reduite/support 3f contraite.PNG

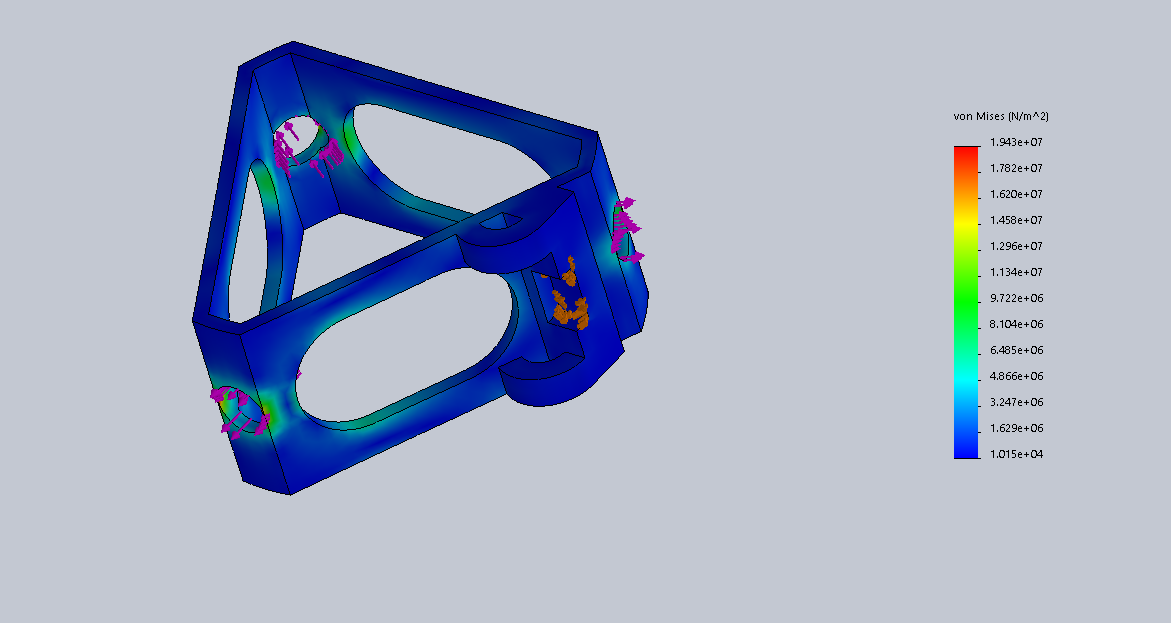
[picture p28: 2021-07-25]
Projets_complets/v2020-2021/RobotTraceur1 - Pierre Gautier - Simon Le Moal - Armand Racine - Gwen Berrou/Conception/Support Crayon/support crayon 3 optimiser/pièce reduite contraite.PNG

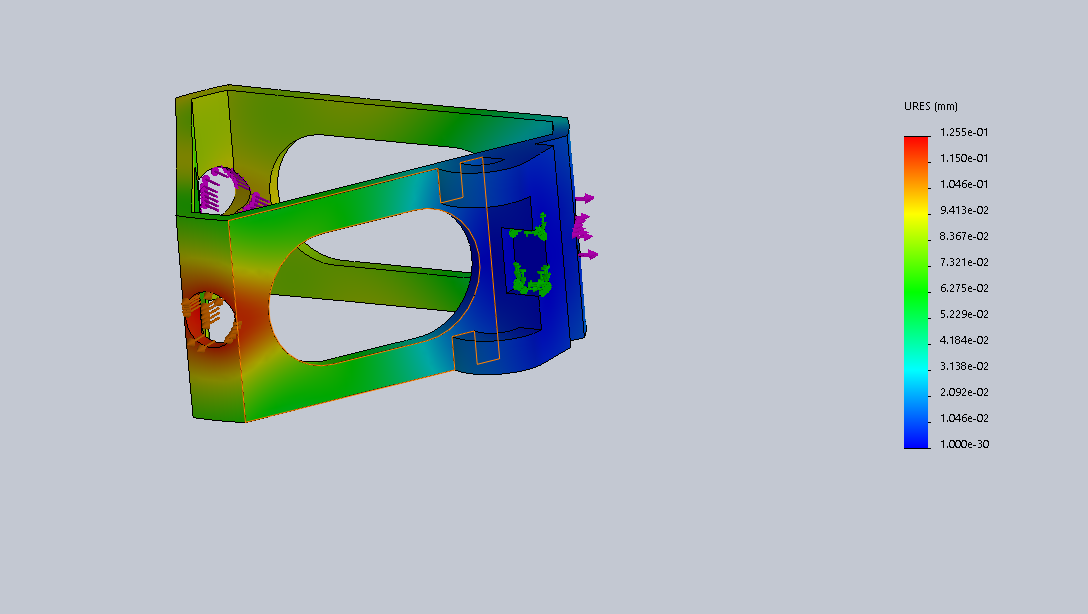
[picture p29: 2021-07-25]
Projets_complets/v2020-2021/RobotTraceur1 - Pierre Gautier - Simon Le Moal - Armand Racine - Gwen Berrou/Conception/Support Crayon/support crayon 3 optimiser/pièce reduite deplacement.PNG

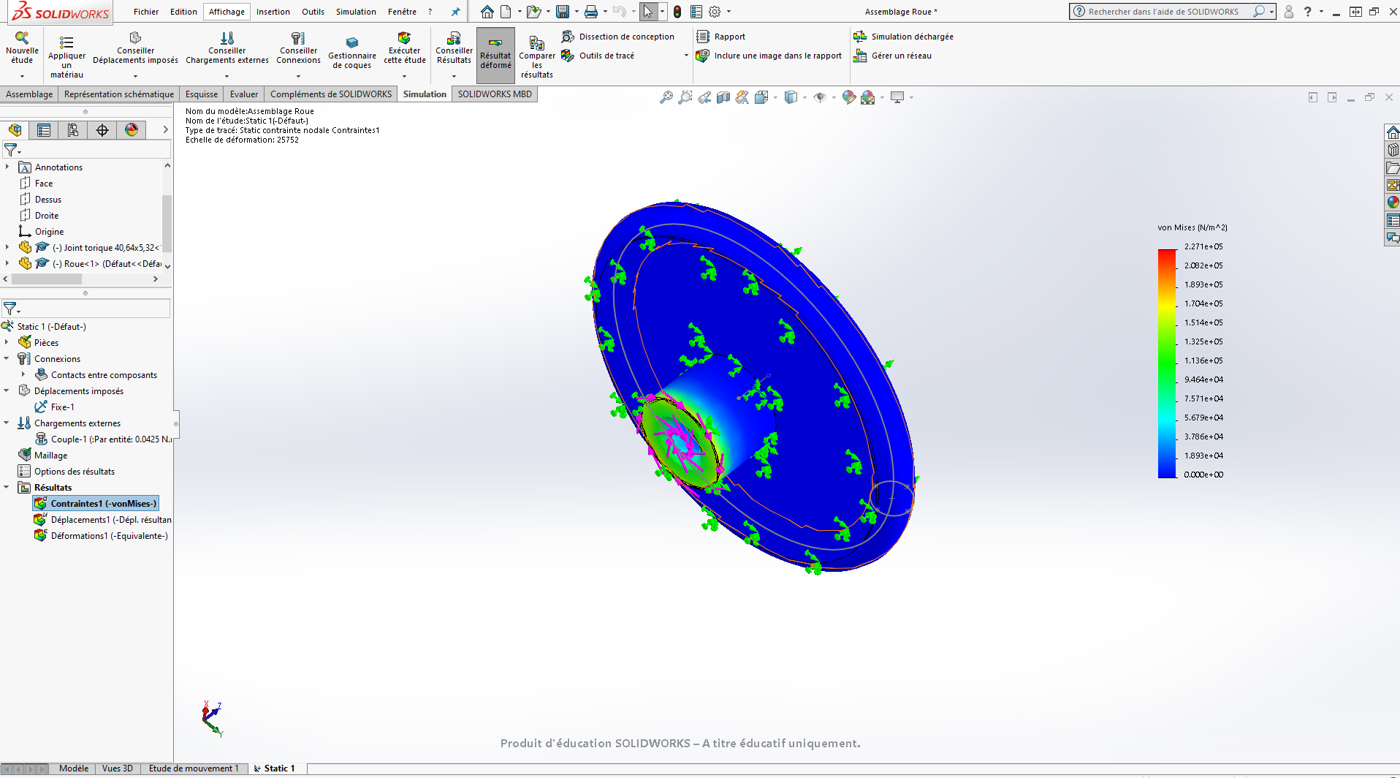
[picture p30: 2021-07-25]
Projets_complets/v2020-2021/RobotTraceur1 - Pierre Gautier - Simon Le Moal - Armand Racine - Gwen Berrou/Conception/Simulations/Roues/contraintes.png

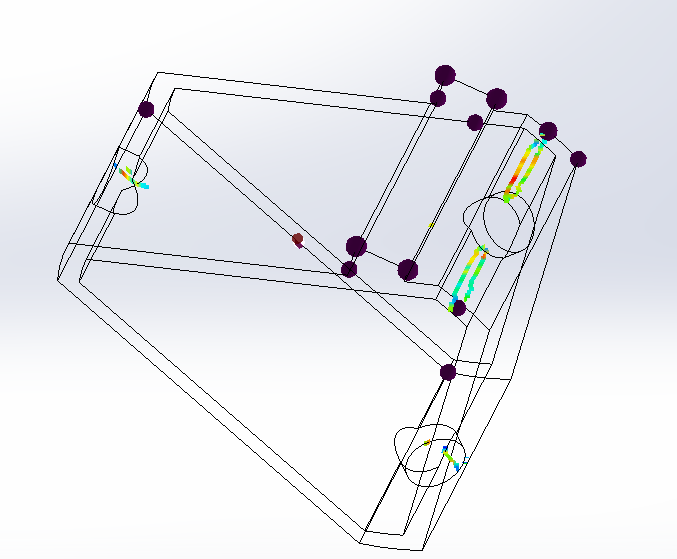
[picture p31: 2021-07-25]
Projets_complets/v2020-2021/RobotTraceur1 - Pierre Gautier - Simon Le Moal - Armand Racine - Gwen Berrou/Conception/Support Crayon/support crayon 2 taille reduite/support injection une.PNG

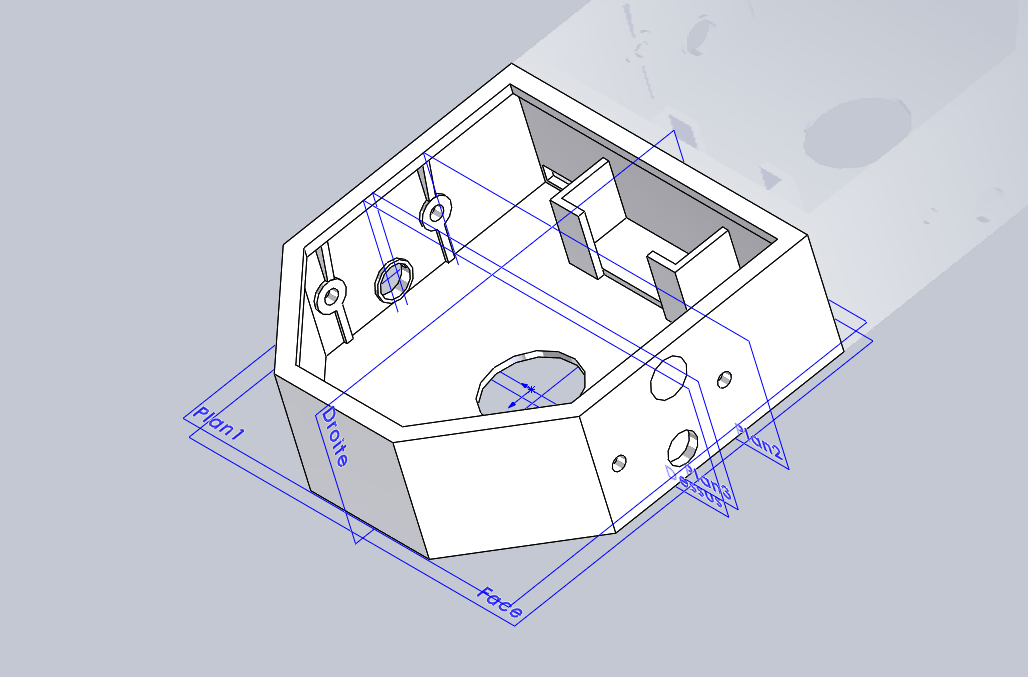
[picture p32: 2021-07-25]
Projets_complets/v2020-2021/RobotTraceur2 - Basile Glo - Gaspar Quéméner - Rahkim Gairbekov - Killian Salmon/Capture des pièces/Chassis.PNG

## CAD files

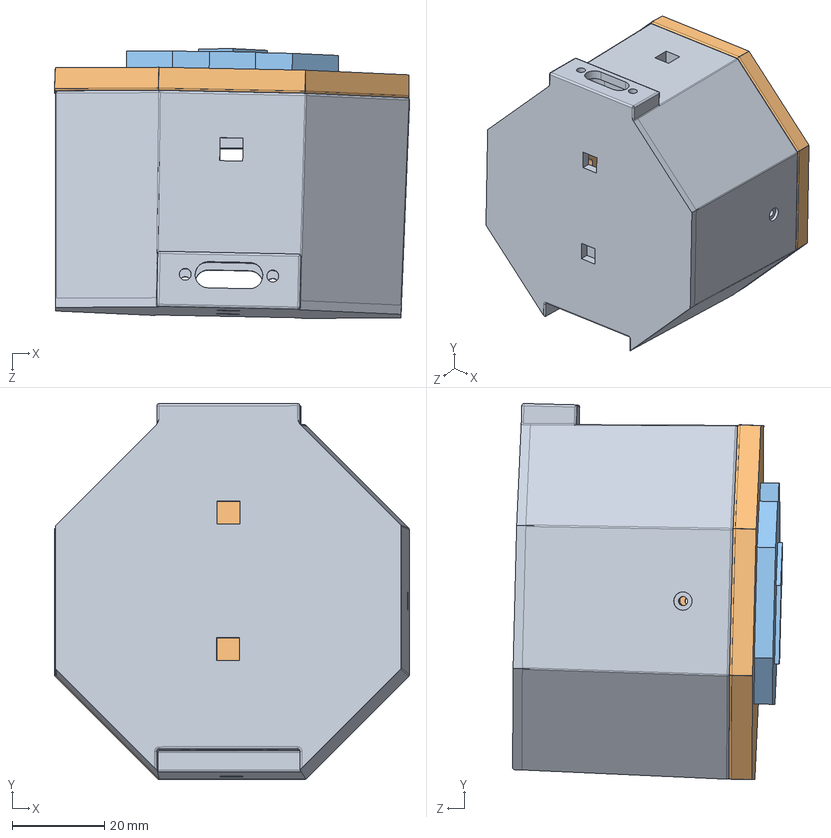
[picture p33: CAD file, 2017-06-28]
Modeles_3D/Solidworks/v2016-2017/Roboblocs-progs/blocprog_et_couvercle.SLDASM
77.0 x 81.6 x 58.5 mm
block
couvercle
fonction tout droit

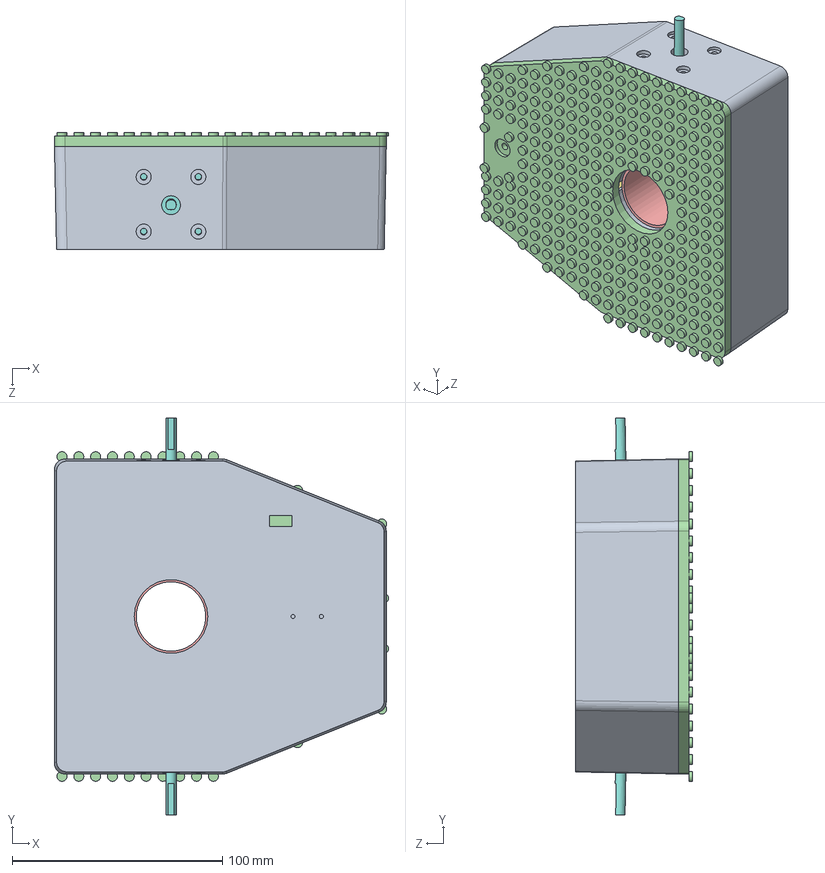
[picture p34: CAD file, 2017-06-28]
Modeles_3D/Solidworks/v2016-2017/Roboblocs-robot/Roboblocs_robot.SLDASM
158.9 x 188.8 x 55.8 mm
Chassis robot
corps batterie.SLDASM
XT60 Connector Female Housing
XT60 Connector Female Contact x 2
Tube translatant v2
servo moteur stylo
griffe de guidage
moteur pas à pas x 2

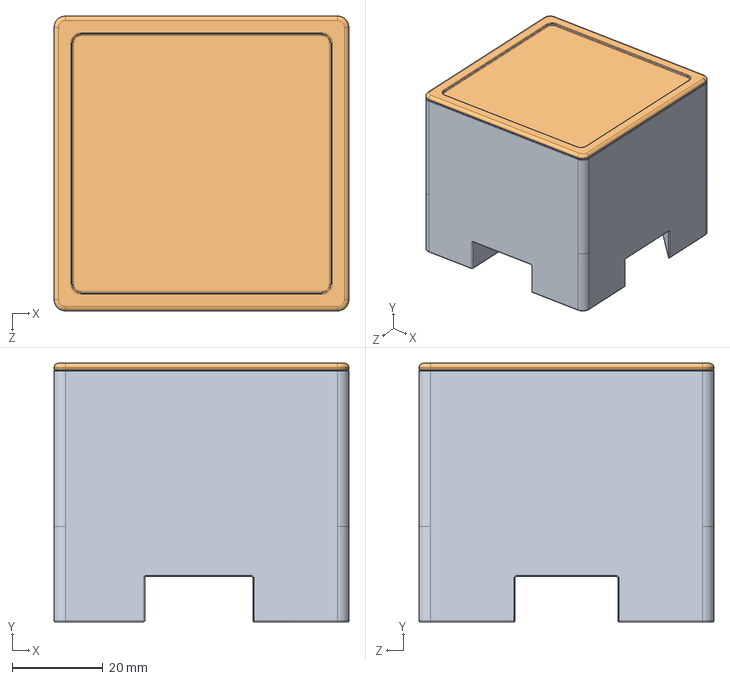
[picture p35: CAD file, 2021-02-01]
Modeles_3D/Solidworks/v2018-2019/Bloc-Prog/Bloc programme.SLDASM
65.0 x 57.0 x 65.0 mm
Blocprog Corps symetrie
Couvercle

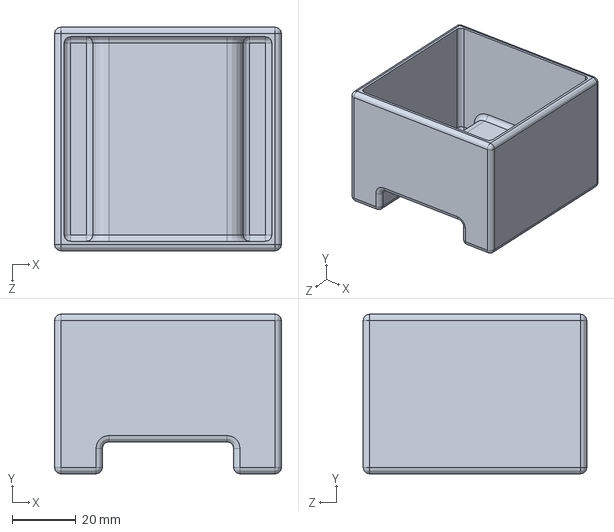
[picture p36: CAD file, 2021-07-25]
Modeles_3D/Solidworks/v2020-2021/BlocsProg1 - Jayson Dauly - Tino Da Costa - Charles Favier/Grand projet PIECE/Assemblage pas fini.SLDPRT
71.0 x 50.0 x 70.0 mm

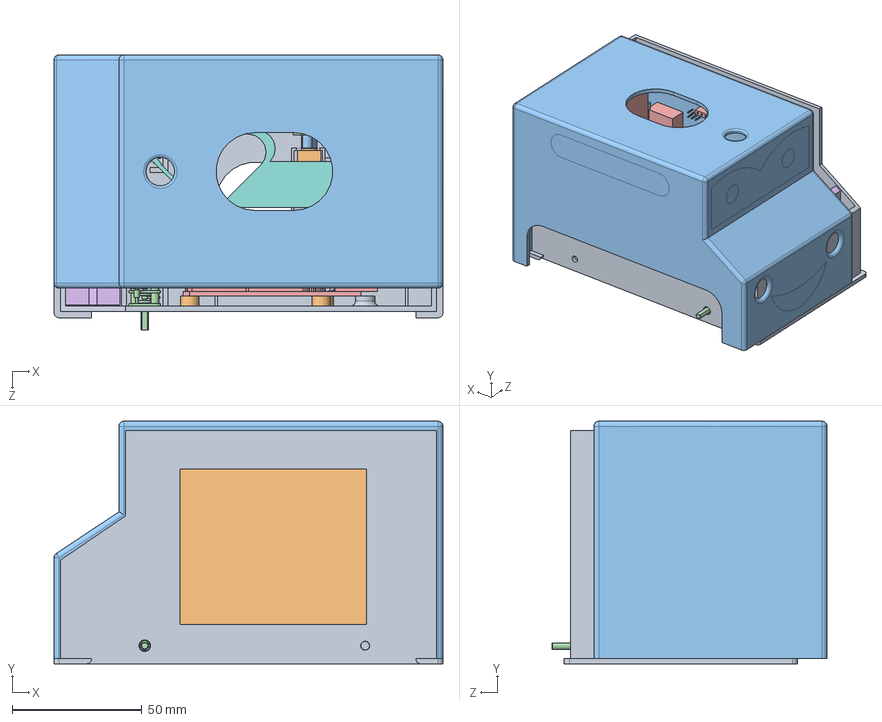
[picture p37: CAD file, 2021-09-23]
Projets_complets/v2020-2021/RobotTraceur4 - Dylan Morilleau - Arthur Albert - Simon Leservoisier - Marius Bourse - Elouan lucas/pièce crayon/Assemblage Robot.SLDASM
150.0 x 93.6 x 106.2 mm
chassis
suppport arduino
Micro Moto Réducteur x 2
Batterie
picèce led
maintien x 2
support crayon
goupille 6mm
servomoteur
piece pignon servomoteur
tige piece servomoteur
atmel

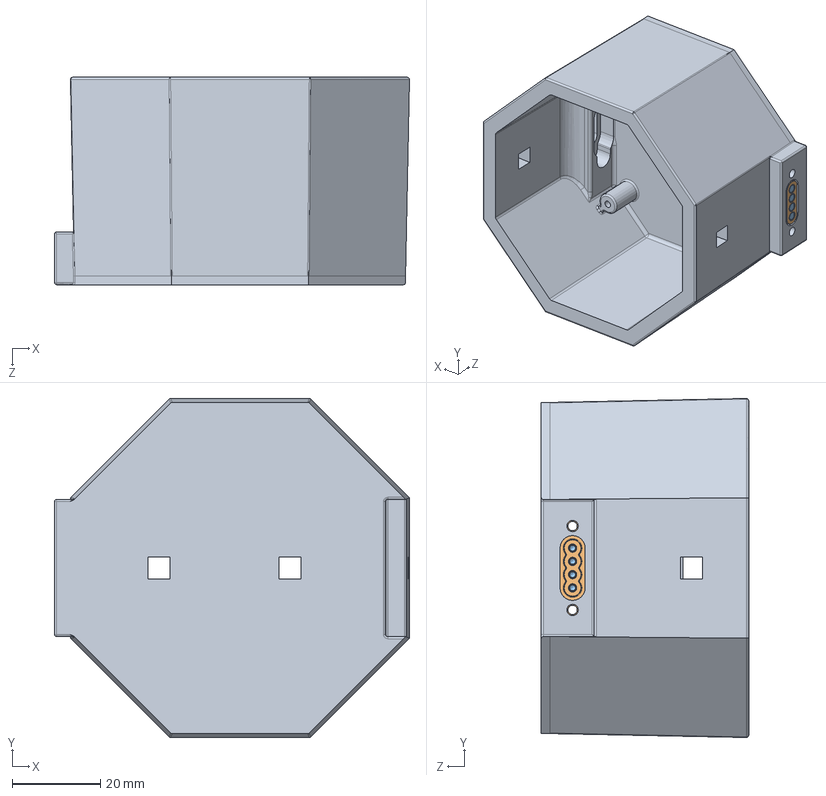
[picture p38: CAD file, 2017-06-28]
Modeles_3D/Solidworks/v2016-2017/Roboblocs-progs/blocprog_seul.SLDASM
80.4 x 76.8 x 47.0 mm
block
land body_4 hole_mini
contact land_sd_mini x 4

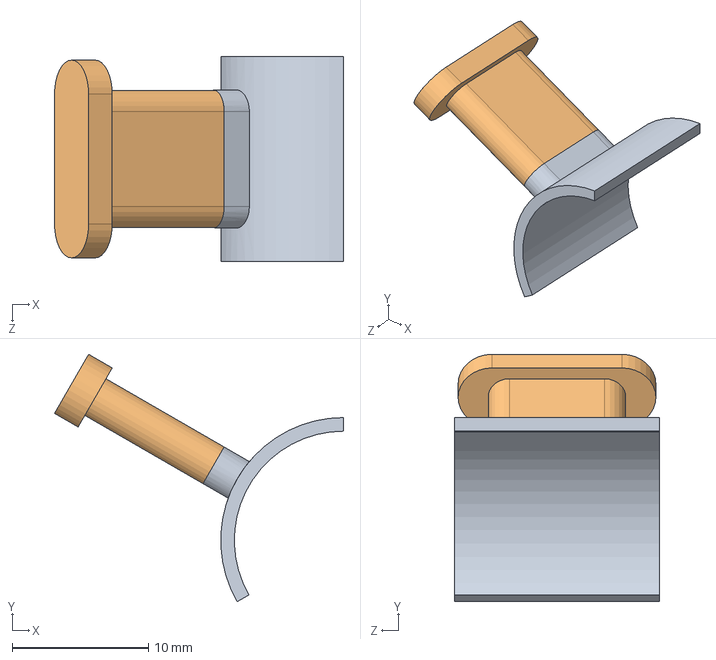
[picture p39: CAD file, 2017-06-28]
Modeles_3D/Solidworks/v2016-2017/Roboblocs-robot/pieces/morts à ressort.SLDASM
21.2 x 18.1 x 15.0 mm
Pièce1
Mort 2

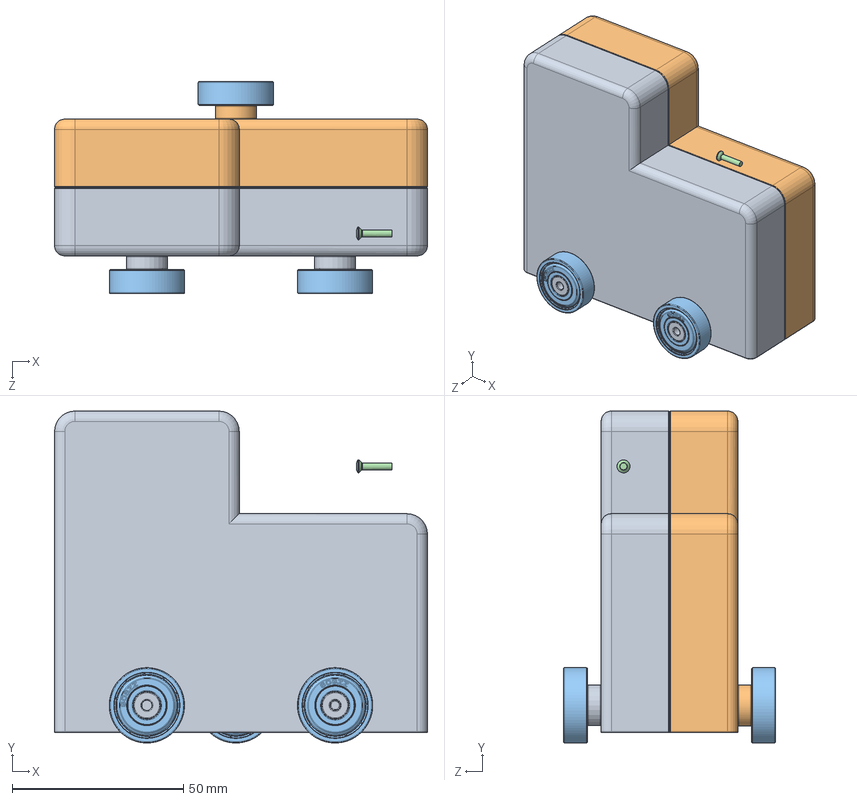
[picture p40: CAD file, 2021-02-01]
Modeles_3D/Solidworks/v2018-2019/Bloc-maître/Assemblage.SLDASM
109.0 x 97.0 x 62.0 mm
coté droit de loco
Symétriecoté droite de loco
Ball Bearing 608ZZ x 3
countersunk raised head cross recess screw_iso

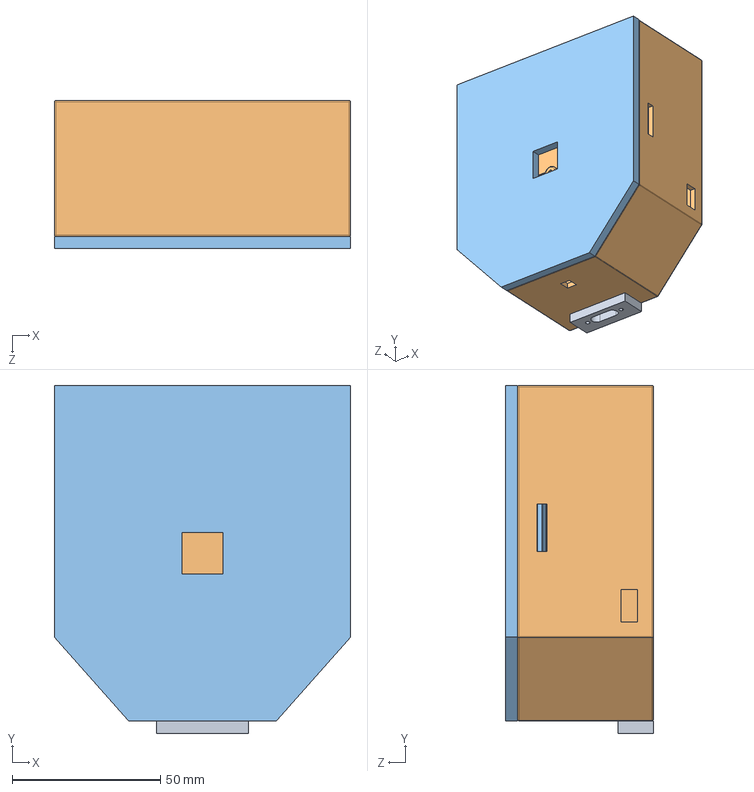
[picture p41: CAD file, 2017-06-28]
Modeles_3D/STEP/v2016-2017/assemblage bloc maître et couvercle finit.STEP
100.0 x 117.5 x 50.0 mm
bloc maître
couvercle bloc maître

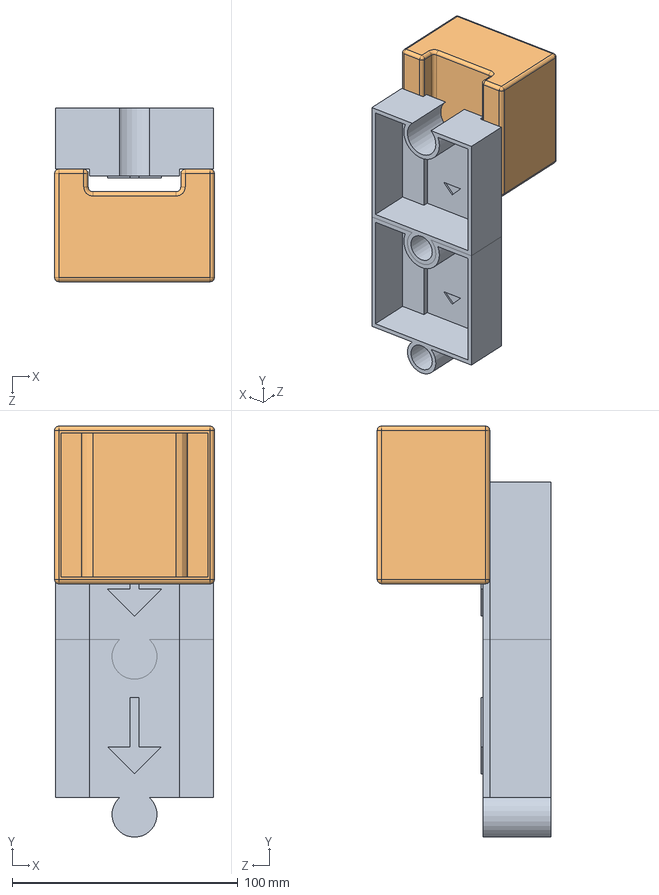
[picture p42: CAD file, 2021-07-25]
Modeles_3D/Solidworks/v2020-2021/BlocsProg1 - Jayson Dauly - Tino Da Costa - Charles Favier/Grand projet PIECE/Assemblage Fin.SLDASM
71.0 x 182.2 x 77.0 mm
1 (Avancé) x 2
Assemblage pas fini

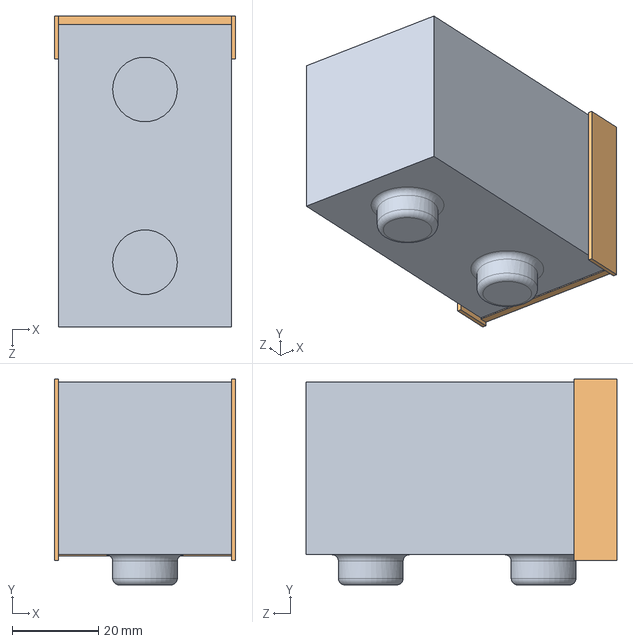
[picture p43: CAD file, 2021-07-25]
Modeles_3D/Solidworks/v2020-2021/BlocsProg2 - Emile Mesnage - Quentin Gallot - Corentin Gloaguen/Solidworks/Conception/Assem1.SLDASM
42.0 x 47.7 x 72.0 mm
Bloc Final projet
Couvercle

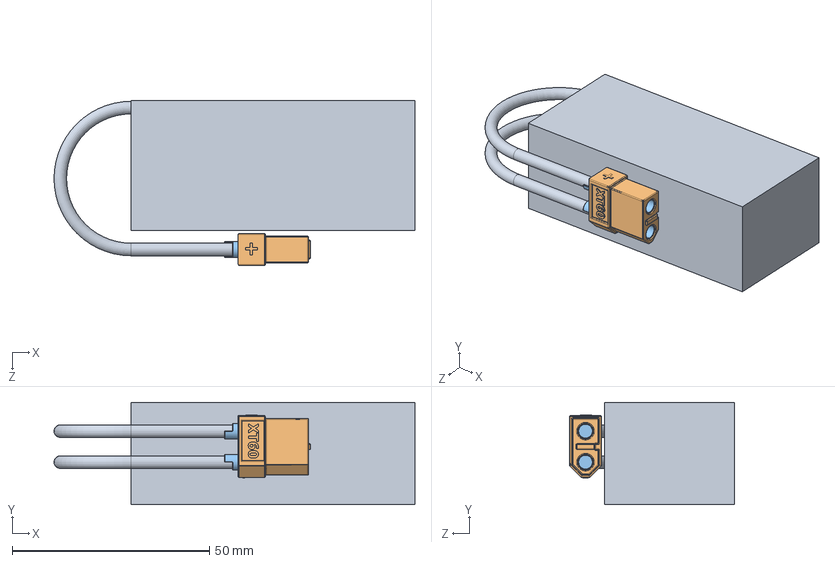
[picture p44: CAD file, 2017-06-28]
Modeles_3D/Solidworks/v2016-2017/Roboblocs-robot/Sous systèmes - composants/Batterie.SLDASM
91.6 x 26.0 x 41.9 mm
corps batterie.SLDASM
XT60 Connector Female Housing
XT60 Connector Female Contact x 2

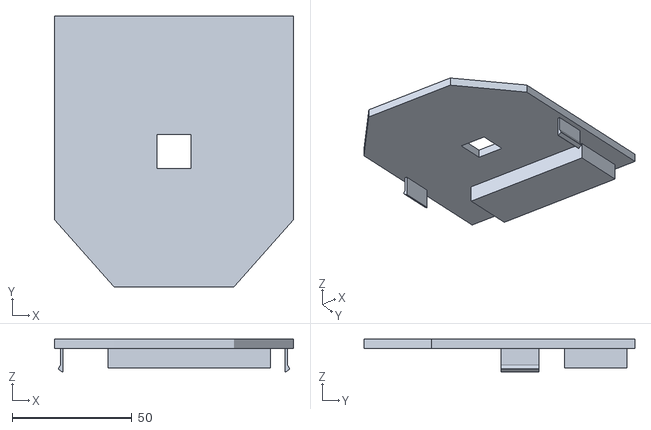
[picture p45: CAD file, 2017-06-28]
Modeles_3D/STL/v2016-2017/assemblage bloc maître et couvercle finit - couvercle bloc maître.STL
100.0 x 113.2 x 13.7

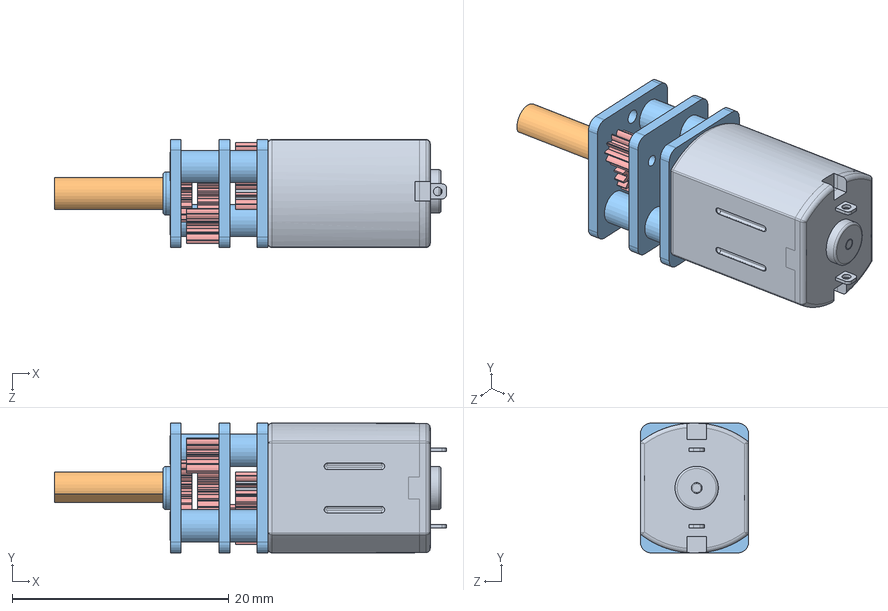
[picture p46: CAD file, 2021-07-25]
Projets_complets/v2020-2021/RobotTraceur1 - Pierre Gautier - Simon Le Moal - Armand Racine - Gwen Berrou/Conception/Pièces 3D/n20 motor.SLDASM
36.2 x 12.0 x 10.0 mm
motor
n20_shaft
n20_gearbox
cross recessed countersunk head screws gb1 x 2
spur gear_gb x 6

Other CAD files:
Modeles_3D/Solidworks/v2016-2017/Roboblocs-maitre/assemblage bloc maître et couvercle finit.SLDASM
Modeles_3D/Solidworks/v2016-2017/Roboblocs-robot/Sous systèmes - composants/corps batterie.SLDASM.SLDPRT
Projets_complets/v2020-2021/RobotTraceur4 - Dylan Morilleau - Arthur Albert - Simon Leservoisier - Marius Bourse - Elouan lucas/pièce crayon/Assemblage_chassis.sldasm
Electronique/protorobotrapido/fixation roue 2.STL
Electronique/protorobotrapido/prototype robot 1.STL
Electronique/protorobotrapido/roue.STL
Modeles_3D/STEP/v2016-2017/SWIFT DOCK MINI-4-SC.STEP
Modeles_3D/STEP/v2016-2017/bloc maître.STEP
Modeles_3D/STEP/v2016-2017/blocprog_et_couvercle.STEP
Modeles_3D/STEP/v2016-2017/blocprog_seul.STEP
Modeles_3D/STEP/v2016-2017/couvercle bloc maître.STEP
Modeles_3D/STL/v2016-2017/Robot - Batterie-1 XT60 Connector Female Connector-1 XT60 Connector Female Contact-1.STL
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

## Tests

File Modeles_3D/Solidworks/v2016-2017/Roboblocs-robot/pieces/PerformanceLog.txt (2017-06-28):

Mesh Preparation:  0 hr 0 min 3 sec
Standard solid mesh total:  0 hr 0 min 9 sec
Beam mesh:  0 hr 0 min 0 sec
Mesh Preparation:  0 hr 0 min 3 sec
Standard solid mesh total:  0 hr 0 min 11 sec
Beam mesh:  0 hr 0 min 0 sec
Mesh Preparation:  0 hr 0 min 0 sec
Standard solid mesh bolt head imprint and hard point processing:  0 hr 0 min 0 sec
Standard solid mesh total preparation including imprint:  0 hr 0 min 0 sec
Standard surface meshing for Solid Mesh:  0 hr 0 min 4 sec
Standard volume meshing for Solid Mesh:  0 hr 0 min 0 sec
Standard solid mesh arranging data:  0 hr 0 min 0 sec
Standard solid mesh total:  0 hr 0 min 4 sec
Beam mesh:  0 hr 0 min 0 sec
Mesh Preparation:  0 hr 0 min 0 sec
Standard solid mesh bolt head imprint and hard point processing:  0 hr 0 min 0 sec
Standard solid mesh total preparation including imprint:  0 hr 0 min 1 sec
Standard surface meshing for Solid Mesh:  0 hr 0 min 4 sec
Standard volume meshing for Solid Mesh:  0 hr 0 min 9 sec
Standard solid mesh arranging data:  0 hr 0 min 1 sec
Standard solid mesh total:  0 hr 0 min 15 sec
Beam mesh:  0 hr 0 min 0 sec
Preparing to transfer data:  0 hr 0 min 0 sec
Processing material properties:  0 hr 0 min 0 sec
Processing element groups:  0 hr 0 min 0 sec
Processing drop test gap nodes:  0 hr 0 min 0 sec
Updating thickness for shell regions:  0 hr 0 min 0 sec
Processing rconst for elements:  0 hr 0 min 0 sec
Processing egroups:  0 hr 0 min 0 sec
Transferring loads and boundary conditions:  0 hr 0 min 0 sec
Generating contacts:  0 hr 0 min 0 sec
Number of Contacts: 0
Transfer SL1 data:  0 hr 0 min 0 sec
Generate simplified contact data:  0 hr 0 min 0 sec
Generate more accurate contact data:  0 hr 0 min 0 sec
Number of contact data: 0
Transfer beam/joint contact data:  0 hr 0 min 0 sec
Transferring other special loads:  0 hr 0 min 0 sec
Transferring bearing loads:  0 hr 0 min 0 sec
Writing Data:  0 hr 0 min 0 sec
Transferring analysis options:  0 hr 0 min 0 sec
Total midsurf mapping:  0 hr 0 min 0 sec

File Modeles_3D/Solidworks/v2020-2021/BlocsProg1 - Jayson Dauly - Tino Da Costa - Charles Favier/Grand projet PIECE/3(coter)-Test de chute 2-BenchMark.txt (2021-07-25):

Host = T015-09

CPU = Intel(R) Celeron(R) CPU G3900 @ 2.80GHz 10000MHz

Number of CPU = 2

Physical Memory = 8GB

OS = Windows 10 19042

SWVersion = SOLIDWORKS 2018_SP2.0

User = daulyj

Mesher Type = CB

Max ElemSize =  0m

Min ElemSize =  0m

Number of Segments =  8

Mesh 0.000 CreateMesh-Start 0 0 0 0 0 0 0 0 0 0 0 0 0 0 0 0 0 0 0 0 0 0 0 0 0 0 0 0

Mesh 0.000 MeshPreprocessing-Start 0 0 0 0 0 0 0 0 0 0 0 0 0 0 0 0 0 0 0 0 0 0 0 0 0 0 0 0

Mesh 0.000 MeshPreparation-Start 0 0 0 0 0 0 0 0 0 0 0 0 0 0 0 0 0 0 0 0 0 0 0 0 0 0 0 0

Mesh 0.033 MeshPreparation-End 0 0 0 0 0 0 0 0 0 0 0 0 0 0 0 0 0 0 0 0 0 0 0 0 0 0 0 0

Mesh 0.033 JointContactCheck-Start 0 0 0 0 0 0 0 0 0 0 0 0 0 0 0 0 0 0 0 0 0 0 0 0 0 0 0 0

Mesh 0.033 JointContactCheck-End 0 0 0 0 0 0 0 0 0 0 0 0 0 0 0 0 0 0 0 0 0 0 0 0 0 0 0 0

Mesh 0.033 MeshPreprocessing-End 0 0 0 0 0 0 0 0 0 0 0 0 0 0 0 0 0 0 0 0 0 0 0 0 0 0 0 0

Mesh 0.033 SolidMesh-Start 0 0 0 0 0 0 0 0 0 0 0 0 0 0 0 0 0 0 0 0 0 0 0 0 0 0 0 0

Mesh 0.328 SetMemoryCopySolid-Start 0 0 0 0 0 0 0 0 0 0 0 0 0 0 0 0 0 0 0 0 0 0 0 0 0 0 0 0

Mesh 0.338 SetMemoryCopySolid-End 0 0 0 0 0 0 0 0 0 0 0 0 0 0 0 0 0 0 0 0 0 0 0 0 0 0 0 0

Mesh 0.338 ImprintAndSplit-Start 0 0 0 0 0 0 0 0 0 0 0 0 0 0 0 0 0 0 0 0 0 0 0 0 0 0 0 0

Mesh 0.348 ImprintAndSplit-End 0 0 0 0 0 0 0 0 0 0 0 0 0 0 0 0 0 0 0 0 0 0 0 0 0 0 0 0

Mesh 0.348 TransferMeshControl-Start 0 0 0 0 0 0 0 0 0 0 0 0 0 0 0 0 0 0 0 0 0 0 0 0 0 0 0 0

Mesh 0.348 TransferMeshControl-End 0 0 0 0 0 0 0 0 0 0 0 0 0 0 0 0 0 0 0 0 0 0 0 0 0 0 0 0

Mesh 0.348 SolidSurfaceMesh-Start 0 0 0 0 0 0 0 0 0 0 0 0 0 0 0 0 0 0 0 0 0 0 0 0 0 0 0 0

Mesh 0.348 SolidSurfaceMesh-Start 0 0 0 0 0 0 0 0 0 0 0 0 0 0 0 0 0 0 0 0 0 0 0 0 0 0 0 0

Mesh 0.902 SolidSurfaceMesh-End 0 0 0 0 0 0 0 0 0 0 0 0 0 0 0 0 0 0 0 0 0 0 0 0 0 0 0 0

Mesh 0.902 SurfaceMeshWriteData-Start 0 0 0 0 0 0 0 0 0 0 0 0 0 0 0 0 0 0 0 0 0 0 0 0 0 0 0 0

Mesh 0.962 SurfaceMeshWriteData-End 0 0 0 0 0 0 0 0 0 0 0 0 0 0 0 0 0 0 0 0 0 0 0 0 0 0 0 0

Mesh 0.962 VolumeMesh-Start 0 0 0 0 0 0 0 0 0 0 0 0 0 0 0 0 0 0 0 0 0 0 0 0 0 0 0 0

Mesh 1.332 VolumeMesh-End 0 0 0 0 0 0 0 0 0 0 0 0 0 0 0 0 0 0 0 0 0 0 0 0 0 0 0 0

Mesh 1.332 VolumeMeshDataRead-Start 0 0 0 0 0 0 0 0 0 0 0 0 0 0 0 0 0 0 0 0 0 0 0 0 0 0 0 0

Mesh 1.762 VolumeMeshDataRead-End 0 0 0 0 0 0 0 0 0 0 0 0 0 0 0 0 0 0 0 0 0 0 0 0 0 0 0 0

Mesh 1.762 MeshDataConstruct-Start 0 0 0 0 0 0 0 0 0 0 0 0 0 0 0 0 0 0 0 0 0 0 0 0 0 0 0 0

Mesh 1.762 NodeMerge-Start 0 0 0 0 0 0 0 0 0 0 0 0 0 0 0 0 0 0 0 0 0 0 0 0 0 0 0 0

Mesh 1.762 NodeMerge-End 0 0 0 0 0 0 0 0 0 0 0 0 0 0 0 0 0 0 0 0 0 0 0 0 0 0 0 0

Mesh 1.762 BadElementChecking-Start 0 0 0 0 0 0 0 0 0 0 0 0 0 0 0 0 0 0 0 0 0 0 0 0 0 0 0 0

Mesh 1.762 BadElementChecking-End 0 0 0 0 0 0 0 0 0 0 0 0 0 0 0 0 0 0 0 0 0 0 0 0 0 0 0 0

Mesh 1.762 GenerateJointContactInfo-Start 0 0 0 0 0 0 0 0 0 0 0 0 0 0 0 0 0 0 0 0 0 0 0 0 0 0 0 0

Mesh 1.762 GenerateJointContactInfo-End 0 0 0 0 0 0 0 0 0 0 0 0 0 0 0 0 0 0 0 0 0 0 0 0 0 0 0 0

Mesh 1.772 MeshDataConstruct-End 0 0 0 0 0 0 0 0 0 0 0 0 0 0 0 0 0 0 0 0 0 0 0 0 0 0 0 0

Mesh 1.825 SolidMesh-End 0 0 0 0 0 0 0 0 0 0 0 0 0 0 0 0 0 0 0 0 0 0 0 0 0 0 0 0

Mesh 1.825 BeamMesh-Start 0 0 0 0 0 0 0 0 0 0 0 0 0 0 0 0 0 0 0 0 0 0 0 0 0 0 0 0

Mesh 1.825 BeamMesh-End 0 0 0 0 0 0 0 0 0 0 0 0 0 0 0 0 0 0 0 0 0 0 0 0 0 0 0 0

Mesh 4.115 CreateMesh-End 0 0 0 0 0 0 0 0 0 0 0 0 0 0 0 0 0 0 0 0 0 0 0 0 0 0 0 0

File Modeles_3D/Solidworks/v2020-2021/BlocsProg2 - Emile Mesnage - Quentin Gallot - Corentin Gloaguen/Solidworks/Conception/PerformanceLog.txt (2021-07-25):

Mesh Preparation:  0 hr 0 min 0 sec
Standard solid mesh bolt head imprint and hard point processing:  0 hr 0 min 0 sec
Standard solid mesh total preparation including imprint:  0 hr 0 min 0 sec
Standard surface meshing for Solid Mesh:  0 hr 0 min 0 sec
Standard volume meshing for Solid Mesh:  0 hr 0 min 0 sec
Standard surface meshing for Solid Mesh:  0 hr 0 min 1 sec
Standard volume meshing for Solid Mesh:  0 hr 0 min 0 sec
Standard solid mesh arranging data:  0 hr 0 min 0 sec
Standard solid mesh total:  0 hr 0 min 2 sec
Beam mesh:  0 hr 0 min 0 sec
Preparing to transfer data:  0 hr 0 min 0 sec
Processing material properties:  0 hr 0 min 0 sec
Processing element groups:  0 hr 0 min 0 sec
Processing drop test gap nodes:  0 hr 0 min 0 sec
Updating thickness for shell regions:  0 hr 0 min 0 sec
Processing rconst for elements:  0 hr 0 min 0 sec
Processing egroups:  0 hr 0 min 0 sec
Transferring loads and boundary conditions:  0 hr 0 min 0 sec
Generating body pairs to check contact:  0 hr 0 min 0 sec
Generating contacts:  0 hr 0 min 0 sec
Number of Contacts: 0
Transfer SL1 data:  0 hr 0 min 0 sec
Generate more accurate contact data:  0 hr 0 min 0 sec
Number of contact data: 0
Transfer beam/joint contact data:  0 hr 0 min 0 sec
Transferring other special loads:  0 hr 0 min 0 sec
Transferring bearing loads:  0 hr 0 min 0 sec
Transferring mass elements:  0 hr 0 min 0 sec
Transferring point loads:  0 hr 0 min 0 sec
Transferring distributed beam loads:  0 hr 0 min 0 sec
Transferring rigid bodies:  0 hr 0 min 0 sec
Transferring component no penetration:  0 hr 0 min 0 sec
Writing Data:  0 hr 0 min 0 sec
Transferring analysis options:  0 hr 0 min 0 sec
Total midsurf mapping:  0 hr 0 min 0 sec

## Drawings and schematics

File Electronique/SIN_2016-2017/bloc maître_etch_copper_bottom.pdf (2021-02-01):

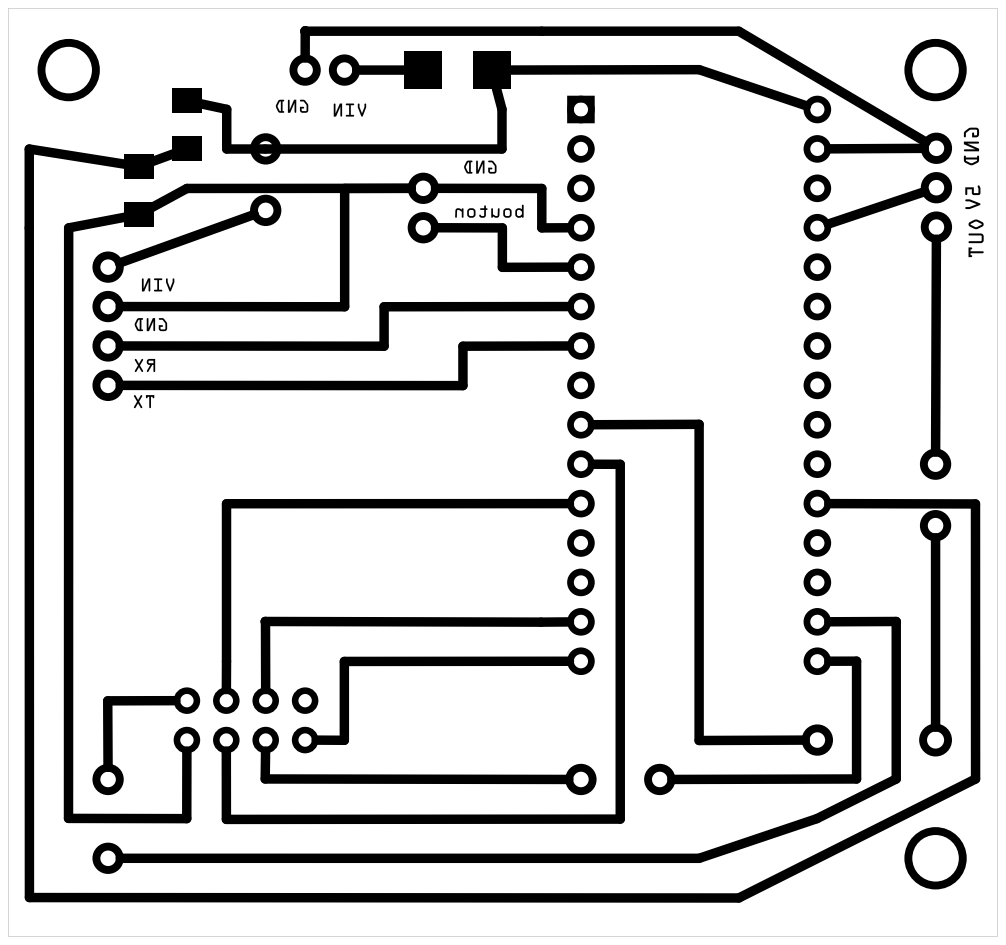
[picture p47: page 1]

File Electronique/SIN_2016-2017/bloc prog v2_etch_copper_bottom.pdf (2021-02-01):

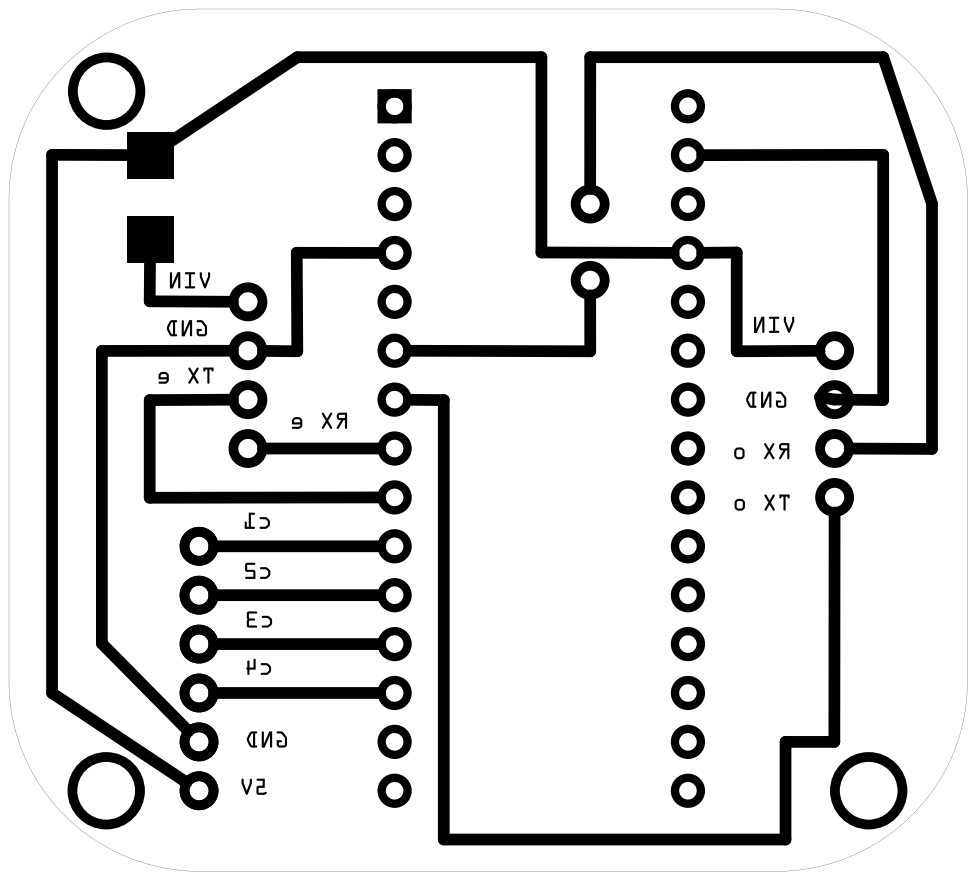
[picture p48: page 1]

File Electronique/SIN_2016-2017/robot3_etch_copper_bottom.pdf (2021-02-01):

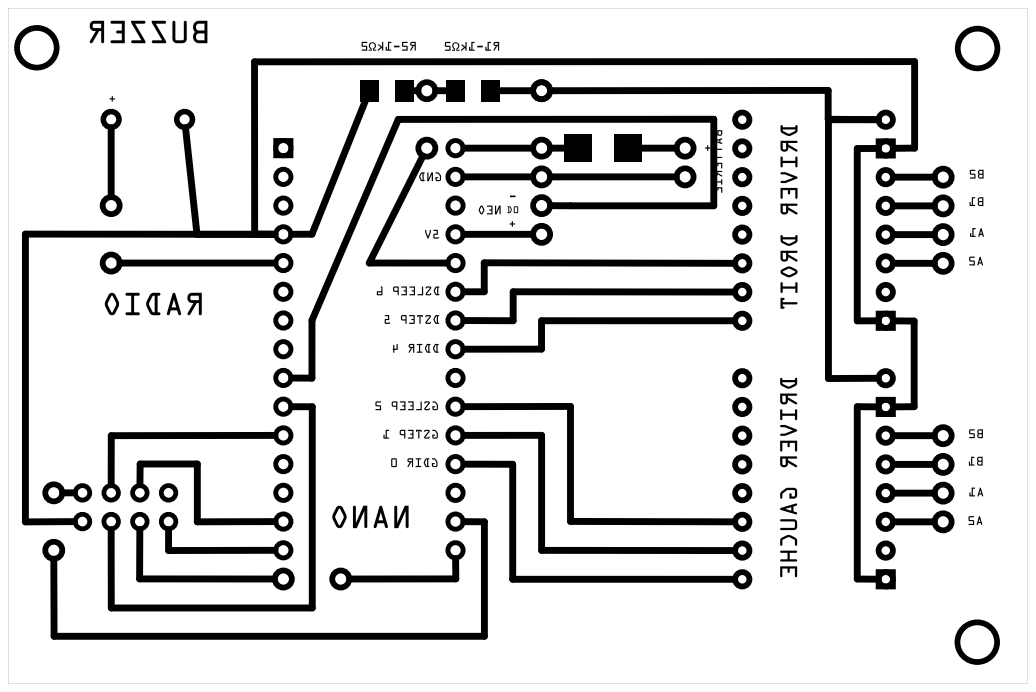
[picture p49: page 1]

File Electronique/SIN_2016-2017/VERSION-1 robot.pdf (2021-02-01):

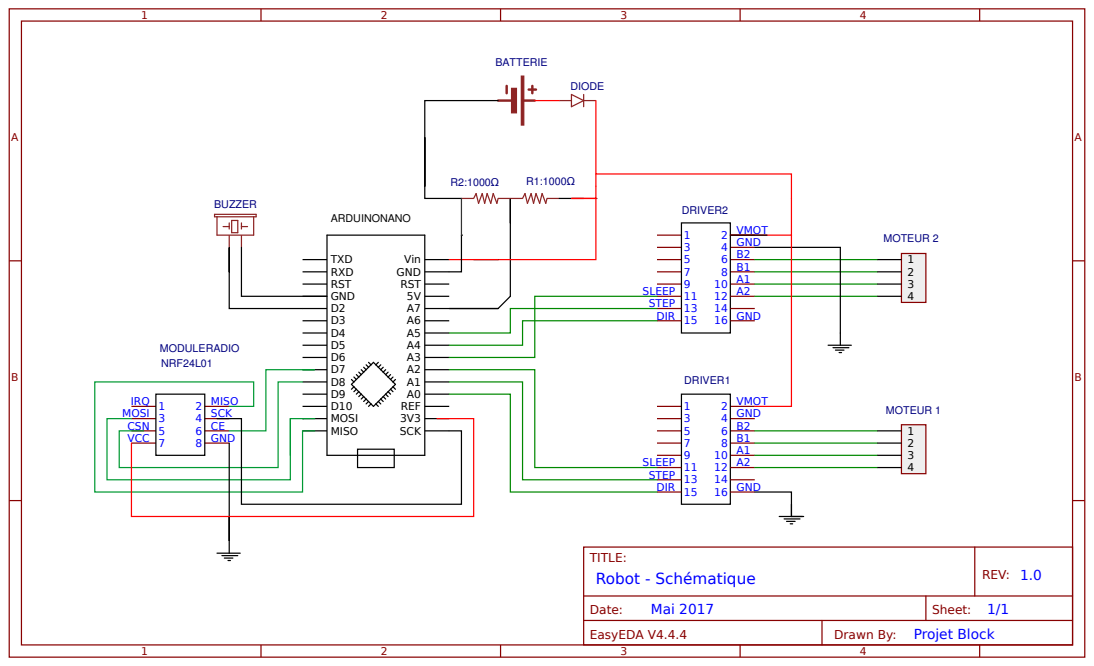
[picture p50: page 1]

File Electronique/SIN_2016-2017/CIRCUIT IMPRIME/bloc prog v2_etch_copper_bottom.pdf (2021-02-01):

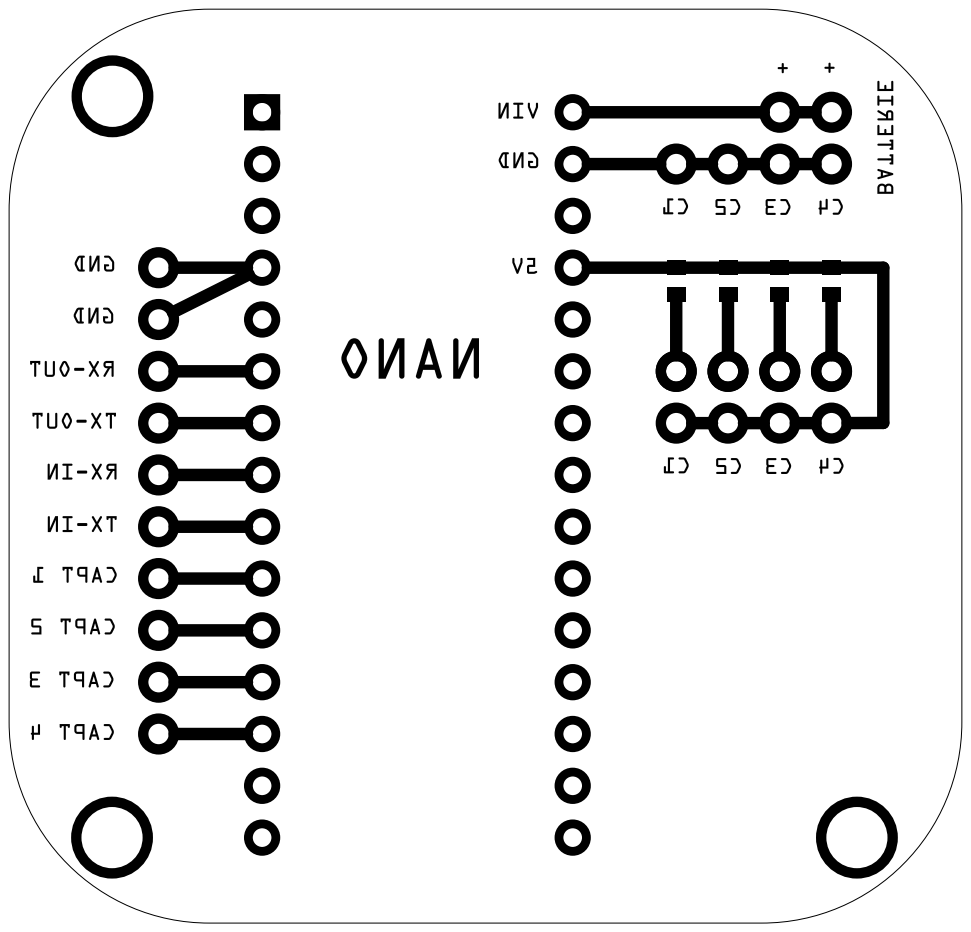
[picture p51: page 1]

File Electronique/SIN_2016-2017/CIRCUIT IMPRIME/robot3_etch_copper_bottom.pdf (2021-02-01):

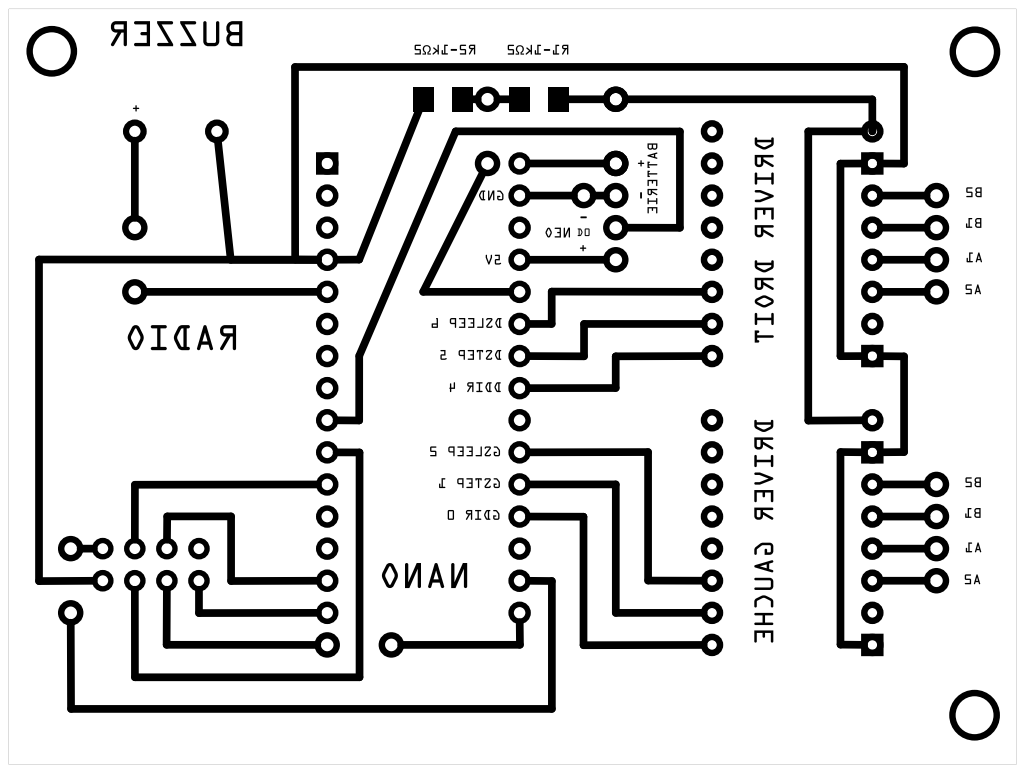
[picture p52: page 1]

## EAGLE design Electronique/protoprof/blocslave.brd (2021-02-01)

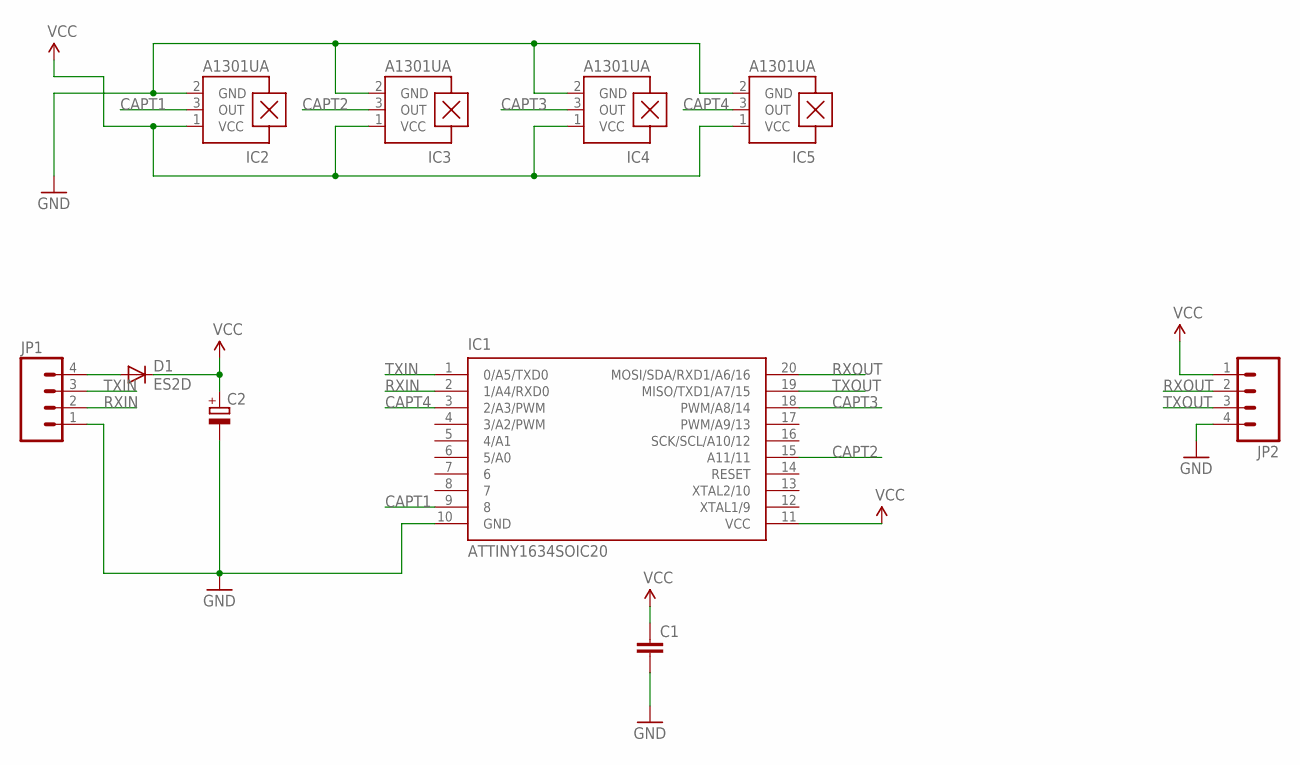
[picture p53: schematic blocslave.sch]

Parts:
C1: C-EUC1206; C1206
C2: CPOL-EUSMCD; SMC_D
D1: ES2D; SMB
IC1: ATTINY1634SOIC20; SOIC20
IC2, IC3, IC4, IC5: A1301UA; SIP3-UA
JP1, JP2: M04; 1X04

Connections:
CAPT1: IC1.9 (8), IC2.3 (OUT)
CAPT2: IC1.15 (A11/11), IC3.3 (OUT)
CAPT3: IC1.18 (PWM/A8/14), IC4.3 (OUT)
CAPT4: IC1.3 (2/A3/PWM), IC5.3 (OUT)
GND: C1.2, C2.-, IC1.10 (GND), IC2.2 (GND), IC3.2 (GND), IC4.2 (GND), IC5.2 (GND), JP1.1, JP2.4
unnamed: D1.A, JP1.4
RXIN: IC1.2 (1/A4/RXD0), JP1.2
RXOUT: IC1.20 (MOSI/SDA/RXD1/A6/16), JP2.2
TXIN: IC1.1 (0/A5/TXD0), JP1.3
TXOUT: IC1.19 (MISO/TXD1/A7/15), JP2.3
VCC: C1.1, C2.+, D1.C, IC1.11 (VCC), IC2.1 (VCC), IC3.1 (VCC), IC4.1 (VCC), IC5.1 (VCC), JP2.1

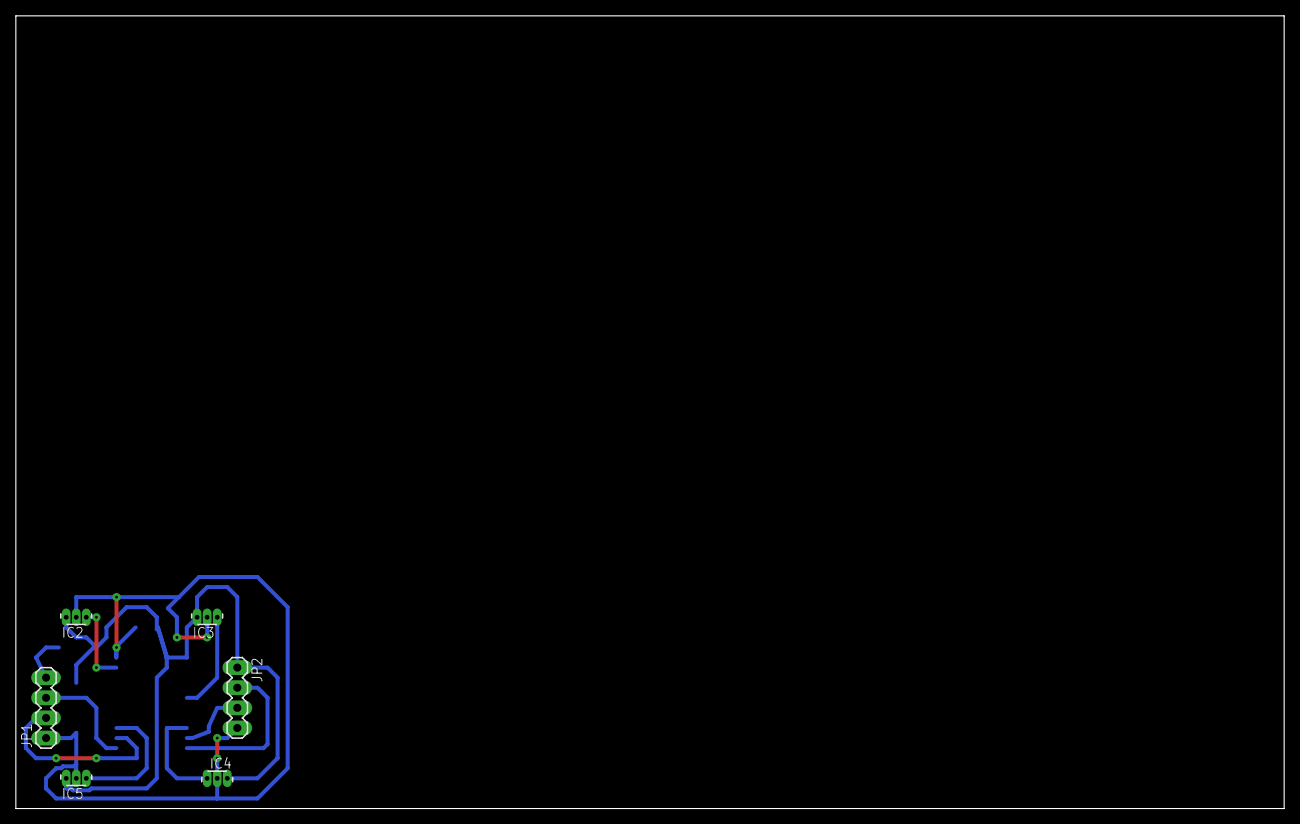
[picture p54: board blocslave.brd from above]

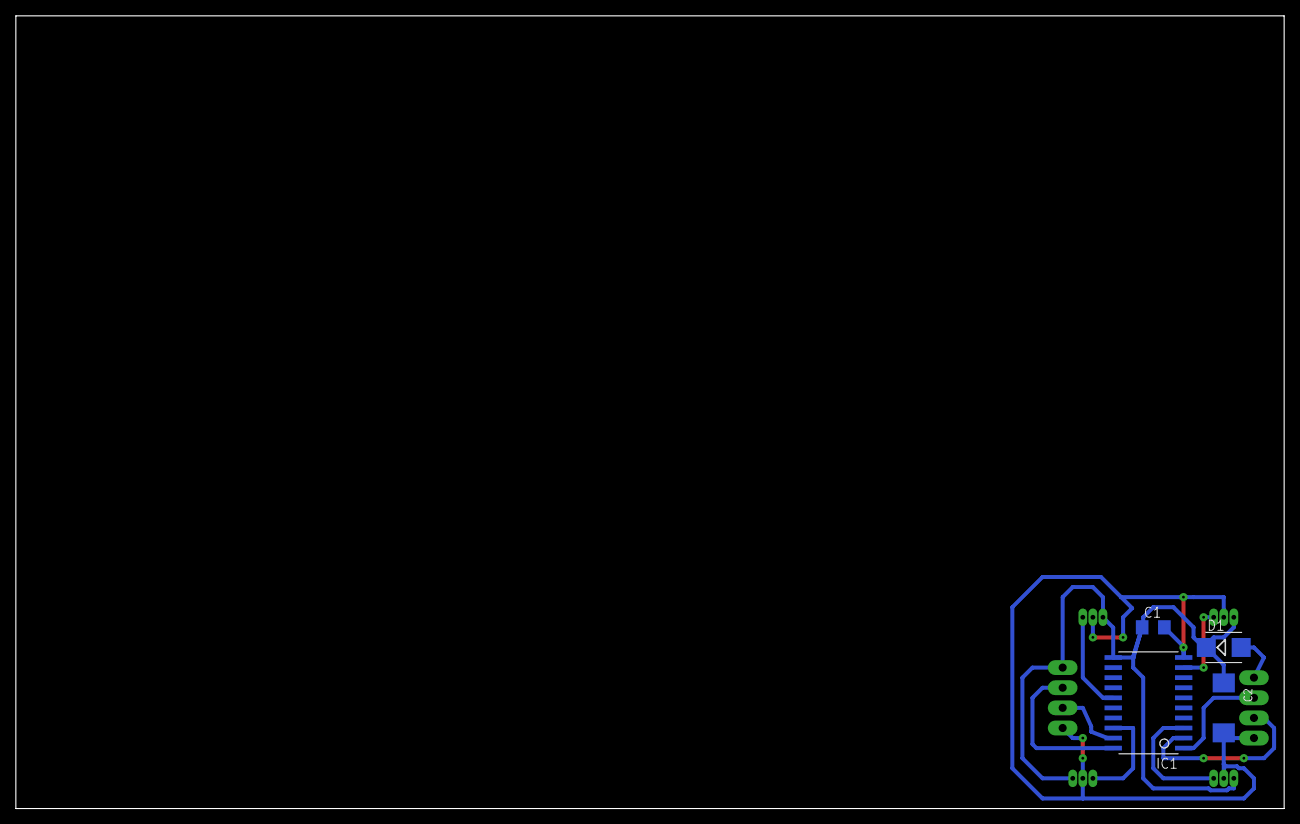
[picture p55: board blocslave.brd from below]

Board: 2 copper layers, 160.0 x 100.0 mm, 10 parts (4 on the bottom side), 11 nets.

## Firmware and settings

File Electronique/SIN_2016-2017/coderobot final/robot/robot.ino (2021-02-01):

const int diametreroue=62;
const int diametrentreroue=177;
const int nbrdepas=1600;
const float pi = 3.14159;
float perimetreroue;
float perimetresol;
float tourentier;
int pas;


int speakerPin = 2;

int dir=A0;
int istep=A1;
int sleep=A2;

int dir2=A4;
int istep2=A5;
int sleep2=A3;

#include <SPI.h>
#include <nRF24L01.h>
#include <RF24.h>
char text;   // on stock dans un tableau
RF24 radio(7, 8); // Broche utilisé pour la communication
const byte rxAddr[6] = "00001";  // adresse

boolean action1 = 0;
boolean action2 = 0;
int x;
char tableau[99];

void setup() {
  pinMode(speakerPin, OUTPUT);
   while (!Serial);
  Serial.begin(9600);
  radio.begin();

  radio.openReadingPipe(0, rxAddr);
  radio.startListening();
  
  Serial.begin(9600);
pinMode(dir,OUTPUT);
pinMode(istep,OUTPUT);
pinMode(sleep,OUTPUT);

pinMode(dir2,OUTPUT);
pinMode(istep2,OUTPUT);
pinMode(sleep2,OUTPUT);
}

void loop() {
  while (action1 == 0) {
    Serial.println("onrecoitrien");

    if (radio.available())  // Si on reçoit quelques choses
    {
      radio.read(&text, sizeof(text));
      Serial.println(text); //lire le texte dans moniteur série
      if (text == 'Z') {
        Serial.println("onrecoitZ");
        radio.setRetries(15, 15);
        radio.openWritingPipe(rxAddr);
        radio.stopListening();
        Serial.println("onecritY");

        radio.write(&("Y"), sizeof("Y"));
        action1 = 1;
      }
    }

  }
  radio.openReadingPipe(0, rxAddr);
  radio.startListening();

  while (action2 == 0) {

    if (radio.available())  // Si on reçoit quelques choses
    {
      Serial.println("onrecoitlesformes");


      radio.read(&tableau[x], sizeof(tableau[x]));
      Serial.println(tableau[x]); //lire le texte dans moniteur série

      if (tableau[x] == 'Z') {
        //dessin des formes
        for (int i = 1; i <= x; i++) {
          switch (tableau[i]) {
            case 'A':
              formeA();
              break;

            case 'B':
              formeB();
              break;

            case 'C':
              formeC();
              break;

            case 'D':
              formeD();
              break;

            case 'E':
              formeE();
              break;

            case 'F':
              formeF();
              break;

            case 'G':
              formeG();
              break;

            case 'H':
              formeH();
              break;

            case 'I':
              formeI();
              break;

            case 'J':
              formeJ();
              break;

            case 'K':
              formeK();
              break;

            case 'L':
              formeL();
              break;

            case 'M':
              formeM();
              break;

            case 'N':
              formeN();
              break;

            case 'O':
              formeO();
              break;

            case 'P':
              formeP();
              break;
          }
        }

        Serial.println("redemarrage dans 5secondes"); //lire le texte dans moniteur série
        delay(5000);
        asm("jmp 0x00");
      }
      x++;
    }
  }
  }

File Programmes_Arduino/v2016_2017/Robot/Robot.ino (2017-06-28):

/*
  Programme du ROBOT

  Ce programme a été conçu pour faire fonctionner le robot
  Il fonctionne avec une carte Arduino NANO mais peut aussi être utilisé avec une carte Arduino UNO.

  Créé l'année scolaire 2016/2017,
  par les élèves de SIN du LYCEE EUGENE LIVET :
  Pierre NICOLAS, Hugo DENIER, Martin POREE et Sullivan LETOUZIC
  N'hésitez pas à nous contacter si vous reprenez le projet à nicolas141299@gmail.com !
*/

//CALCULS DES ANGLES
const int diametreroue = 62; // Diamètre de la roue
const int diametrentreroue = 177; // Diamètre du cercle crée par la rotation du robot
const int nbrdepas = 1600; // Nombre de pas d'un moteur
const float pi = 3.14159;
float perimetreroue;
float perimetresol;
float tourentier;
int pas;
//--------------

//BUZZER
int speakerPin = 2; // Le buzzer est branché sur la pin 7
//--------------

//MOTEURS
int dir = A0;
int istep = A1;
int sleep = A2;
int dir2 = A4;
int istep2 = A5;
int sleep2 = A3;
//--------------

//RADIO
// ATTENTION MODULE NRF24L01 SUR 3.3V !!!
#include <SPI.h>
#include <nRF24L01.h>
#include <RF24.h>
char text;
RF24 radio(7, 8); // CE, CSN CE sur la pin 7 et CSN sur la pin 8
const byte rxAddr[6] = "00001";

//VARIABLE
boolean action1 = 0;
boolean action2 = 0;
int x;
char tableau[99];
//--------------

//SERVOMOTEUR
#include <Servo.h>
Servo servo;
//--------------

void setup() {
  //BUZZER
  pinMode(speakerPin, OUTPUT);
  //--------------

  //COMMUNICATION PC
  while (!Serial);
  Serial.begin(9600);
  Serial.println("Robot operationnel !");
  //--------------

  //COMMUNICATION RADIO
  radio.begin();
  radio.openReadingPipe(0, rxAddr);
  radio.startListening();
  //--------------

  //MOTEURS
  pinMode(dir, OUTPUT);
  pinMode(istep, OUTPUT);
  pinMode(sleep, OUTPUT);
  pinMode(dir2, OUTPUT);
  pinMode(istep2, OUTPUT);
  pinMode(sleep2, OUTPUT);
  //--------------
  
  //SERVOMOTEUR
myservo.attach(6);  // Le servo est branché sur la pin 6
}

void loop() {
  while (action1 == 0) { // BOUCLE POUR SAVOIR VALIDER AU BLOC MAITRE QU'ON EST LA
    Serial.println("On recoit rien");
    if (radio.available())
    {
      radio.read(&text, sizeof(text));
      Serial.println(text);
      if (text == 'Z') { // ON RECOIT Z POUR SAVOIR SI ON EST LA
        Serial.println("onrecoitZ");
        radio.setRetries(15, 15);
        radio.openWritingPipe(rxAddr);
        radio.stopListening();
        Serial.println("onecritY");

        radio.write(&("Y"), sizeof("Y")); // ON REPOND
        action1 = 1;
      }
    }
  }

  radio.openReadingPipe(0, rxAddr);
  radio.startListening();
  while (action2 == 0) { // BOUCLE POUR RECEVOIR LES FORMES
    if (radio.available())
    {
      Serial.println("on recoit les formes");
      radio.read(&tableau[x], sizeof(tableau[x])); // ON STOCKE LES FORMES
      Serial.println(tableau[x]);

      if (tableau[x] == 'Z') { // ON RECOIT Z ALORS LA COMMUNICATION EST TERMINEE
        for (int i = 1; i <= x; i++) { // ON INTERPRETE LES CARACTERES EN FORME POUR LES DESSINER
          switch (tableau[i]) {
            case 'A':
              formeA();
              break;

            case 'B':
              formeB();
              break;

            case 'C':
              formeC();
              break;

            case 'D':
              formeD();
              break;

            case 'E':
              formeE();
              break;

            case 'F':
              formeF();
              break;

            case 'G':
              formeG();
              break;

            case 'H':
              formeH();
              break;

            case 'I':
              formeI();
              break;

            case 'J':
              formeJ();
              break;

            case 'K':
              formeK();
              break;

            case 'L':
              formeL();
              break;

            case 'M':
              formeM();
              break;

            case 'N':
              formeN();
              break;

            case 'O':
              formeO();
              break;

            case 'P':
              formeP();
              break;
          }
        }
        Serial.println("redemarrage dans 5secondes"); // TOUTES LES FORMES ONT ETE REPRODUITE; ON RESET LA CARTE
        delay(5000);
        asm("jmp 0x00");
      }
      x++;
    }
  }
}

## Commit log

2017-06-28 upload arduino programs
2017-06-28 3D models
    [Robot - Batterie-1 XT60 Connector Female Connector-1 XT60 Connector Female Contact-1.STL, Robot - Batterie-1 XT60 Connector Female Connector-1 XT60 Connector F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]
2017-06-28 solidworks models
    [10 PORT HEADER.SLDPRT, 102 RESISTOR PACK.SLDPRT, 102 RESISTOR PACK.sldprt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]
2021-02-01 nettoyage + rajout versions
    [!Assemblage final.SLDASM, !Robot_assemblage.SLDASM, 10 PORT HEADER.SLDPRT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]
2021-07-25 add v2020-2021
    [1 (Avancé).SLDPRT, 2 (Coter).SLDPRT, 3(coter).SLDPRT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]
2021-09-23 add Robot
    [Assem1.SLDASM, Assemblage Robot.SLDASM, Assemblage_chassis.sldasm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]

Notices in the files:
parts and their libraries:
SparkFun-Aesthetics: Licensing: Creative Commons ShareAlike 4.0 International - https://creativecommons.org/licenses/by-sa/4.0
